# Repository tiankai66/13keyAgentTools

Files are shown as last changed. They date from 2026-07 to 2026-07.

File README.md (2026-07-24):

# 13keyAgentTools

一个面向 Codex、Claude Code、Qoder 等终端工具的开源宏键盘。它本质上是一个可编程宏按键设备，通过标准 USB HID 和可选 USB CDC 与不同 Agent 工作流配合。

本项目采用“3D 打印外壳 + Arduino Micro 手焊 + 可替换固件”的第一版路线，不要求先设计定制 PCB。目标是先做出可靠的通用宏键盘，再逐步增加多 Agent 状态同步、配置工具和可选专用 PCB。

## 当前方案

- 主控：Arduino Micro 兼容板，ATmega32U4，5V / 16MHz，USB-C 数据接口
- 输入：13 键矩阵、1 个 EC11 音量旋钮
- 输出：USB HID 键盘；面板 12 颗独立 RGB 灯显示当前 Agent 剩余用量
- 外壳：OpenSCAD 参数化封闭式盒体，PLA/PETG 3D 打印；紧凑布局
- 固件：Arduino IDE MVP；稳定后迁移到 QMK/Vial
- 主机端：USB CDC 串口状态测试工具；后续接入各 Agent 的 hooks、CLI 事件或桌面自动化

## 目录

```text
13keyAgentTools/
├── mechanical/       3D 打印建模、参数、公差和打印记录
├── hardware/         BOM、手焊接线、测试计划
├── firmware/         Arduino Micro 固件和后续 QMK 迁移位置
├── host/             主机端 RGB 状态桥接和测试工具
├── docs/             工程决策、版本记录和迭代流程
└── .github/          自动检查
```

## 快速开始

1. 先阅读面向新手的 [硬件装配指南](docs/BEGINNER_BUILD_GUIDE.md)，再阅读 [硬件接线说明](hardware/wiring/README.md)。
2. 将 [公差件 STL](mechanical/exports/tolerance_coupon.stl) 导入 Bambu Studio，先验证轴孔和 M3 铜螺母配合。
3. 将 [灯珠承载条](mechanical/exports/pixel_carrier.stl)、[主板透明窗](mechanical/exports/window_lens.stl)、[定位板 STL](mechanical/exports/plate.stl) 和 [下层面板 STL](mechanical/exports/bottom.stl) 导入切片器打印；参数见 [打印计划](mechanical/print/PRINT_PLAN.md)。
4. 也可以用 OpenSCAD 打开 `mechanical/cad/agent_macro.scad`，或运行 `make cad-export` 重新生成 STL。
5. 打印外壳和定位板，先安装 6 个按键、1 个旋钮和 12 颗 RGB 灯中的一小段进行验证。
6. 在 Arduino IDE 中打开 `firmware/arduino/agent_macro_mvp/agent_macro_mvp.ino`。
7. 选择 `Arduino Micro`，上传固件后逐个验证按键、旋钮和面板 RGB 灯。
8. 安装主机端测试工具：

   ```bash
   python3 -m venv .venv
   . .venv/bin/activate
   pip install -r host/agentd/requirements.txt
   python host/agentd/agentd.py --list
   ```

## 版本路线

### Rev 0.1：手焊 MVP

- 6 个按键
- 旋钮
- 单颗 RGB 灯
- Arduino `Keyboard.h`
- 串口发送测试灯效

### Rev 0.2：完整输入设备和用量反馈

- 13 键矩阵和 13 个 1N4148 二极管
- 工作旋钮、音量旋钮、摇杆、TTP223
- 前侧 12 灯 quota 灯带
- PETG 外壳和底壳
- Accept / Reject 使用长按保护

### Rev 0.3：紧凑灯效版

- 移除中心指托，缩短外壳尺寸
- 增加音量 EC11 旋钮
- 12 颗独立可编址 RGB 灯按颗排列，支持用量条渐变显示

### Rev 0.4：面板灯和单旋钮版

- 采用 13 个按键 + 1 个音量旋钮的蓝图式布局
- 移除摇杆、触摸区和多余控制开孔
- 将 12 颗 RGB 灯移到键盘面板，使用一个数据引脚串联控制

### Rev 0.5：按键下置控制板版

- 外壳收缩到约 120 × 100 mm
- 底壳高度增加到 24 mm
- Arduino Micro 放在按键区下方的承托架上
- 右侧只保留窄灯珠轨和音量旋钮，不保留大块空白控制区

### Rev 0.6：双层分体面板版

- 左侧上层面板承载 13 个按键、水平灯带和旋钮
- 右侧示意的下层面板固定 Arduino Micro
- 两块 120 × 95 mm 面板用四角 M3 支柱连接，方便打印、焊接和检修

### Rev 0.6.1：右侧红框主板位

- Arduino Micro 移到右侧空白区下方，避免与按键矩阵重叠
- USB 开口改到右后侧，利用现有空白体积，不增加按键区高度

### Rev 0.7：USB-C 主控接口

- Arduino Micro 兼容板改为 USB-C 数据接口
- 右后侧上、下层面板开口按约 16 × 7 mm 重新导出
- 引脚、固件和矩阵/RGB 接线保持不变，仅更换主控板接口和 USB-C 数据线

### Rev 0.8：前侧供电和主板观察窗

- USB-C 入口调整到图示前侧上边缘，音量旋钮保持在下方
- 右侧主板区域增加透明观察窗
- 13 个按键整体向内收，增加与四角 M3 螺丝的安全距离

### Rev 0.8.1：紧凑 EC11 窗口

- 根据实物照片将旋钮窗口调整为约 12.5 × 12.5 mm 圆角开口
- 保留立式 EC11 结构，缩小窗口而不改变旋钮位置和接线

### Rev 0.8.2：6mm 圆形旋钮轴孔

- 按实物规格将旋钮口改为圆形 6mm 轴孔
- STL 按 6.2mm 导出，适配 FDM 打印公差

### Rev 0.9.4：实测主控与封闭式盒体

- 主控按实物尺寸 35 × 18 × 10 mm 建模，平放在下层盒体内部。
- 下层改为 2.4 mm 底板、16 mm 高的封闭盒底，左右导轨、后挡块和前侧盒壁共同卡住主板。
- Type-C 改为下层前墙 14 × 9 mm 插口，插头从盒体前侧直进，不再依赖上层面板的悬空开口。
- 主板透明窗配套 25.4 × 51.4 × 1.5 mm 透明片，从下方安装后与上层面板一起封闭内部空间；整机装配后是完整盒体。

### Rev 0.3：多 Agent 状态桥

- 主机端接收 Codex、Claude Code、Qoder 等 Agent 的状态
- Raw HID 或 USB CDC 状态协议
- 每个 Agent 独立颜色和等待/运行/完成状态

### Rev 1.0：专用 PCB

- 先保留 Arduino Micro 插座或排针
- 验证无误后再考虑裸 MCU 和集成 USB-C

## 工程原则

- 每个硬件修改先更新 `hardware/wiring/` 和 BOM。
- 每次打印保留耗材、层高、尺寸偏差和照片记录。
- 每次固件修改记录在 `docs/ITERATION_LOG.md`。
- 不把 OpenAI、Anthropic、Qoder、Work Louder 等商标或图标作为项目品牌或商品标识。

## 许可证

本项目新增代码、CAD 和文档默认采用 MIT License，见 [LICENSE](LICENSE)。第三方库和参考项目仍遵循其各自许可证。

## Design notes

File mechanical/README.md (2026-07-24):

# 3D 打印建模

当前使用 OpenSCAD 做参数化 Rev 0.9.4。模型拆成上层控制盖和下层封闭盒底：先打印公差件，再打印灯珠承载条、透明窗、上层控制盖和下层盒体。

## 文件

- `cad/agent_macro.scad`：上层控制盖、下层封闭盒体、主控卡槽、装配预览和公差件。
- `exports/`：可直接导入 Bambu Studio、PrusaSlicer 或 Cura 的 STL 文件。
- `../docs/media/assembly_walkthrough.mp4`：面向新手的封闭盒体装配视频。
- `exports/pixel_carrier.stl`：固定 12 颗独立 RGB 灯珠的承载条。
- `exports/window_lens.stl`：封闭主板观察窗的透明 PETG 镜片；追求清晰度时优先使用亚克力片。
- `tools/generate_stl.py`：无 GUI 环境下的可重复 STL 导出脚本。
- `print/PRINT_PLAN.md`：切片、打印顺序和验收记录模板。

## 设计基准

- 两块面板尺寸：120 × 95 mm。
- 按键间距：19.05 mm。
- MX 轴孔初始尺寸：14.0 mm。
- 上盖厚度：3 mm。
- 下层盒体底板厚度：2.4 mm；盒体高度 16 mm，和 3 mm 上层控制盖装配后总高约 19 mm。
- Arduino Micro 按 35 × 18 × 10 mm 平放，卡槽左右各留 0.6 mm，侧向导轨和后挡块防止主板移动。
- Type-C 插口位于下层盒体前墙，开口约 14 × 9 mm；上层控制盖不再承担 USB 插座受力。
- EC11 使用立式/垂直轴安装，轴线垂直于 3 mm 上层面板；本模型不兼容卧式/侧插编码器。
- 按照片中的小型 EC11 优化为圆形约 6.2 mm 轴孔，适配标称 6 mm 轴，不再使用偏大的方形窗口。
- 上层控制盖右侧保留 24 × 50 mm 主板透明观察窗；透明片改为 25.4 × 51.4 × 1.5 mm，从下方压住窗口边缘，完成封闭。
- 固定方式：M3 螺丝 + 热熔铜螺母。
- 面板 quota RGB 灯：12 个独立窗口，间距 5.3 mm。

这些数值是 Rev 0.9.4 的首件打印基准。主控必须实测为 35 × 18 × 10 mm；不同 USB-C 插座位置的兼容板不能直接套用，先打印公差件和下层盒体做干涉确认。

## 导出

在 OpenSCAD 顶部修改：

```scad
part = "plate";     // plate / bottom / controller_panel / assembly / tolerance / pixel_carrier
```

按 `F6` 渲染后导出 STL。当前 Rev 0.9.4 的 STL 已提交到 `mechanical/exports/`，方便直接下载和导入切片器。为兼容原有链接，`plate.stl` 表示上层控制盖，`bottom.stl` 表示下层封闭盒体。

如果 OpenSCAD 命令行不可用，可安装脚本依赖后执行：

```bash
python3 -m venv /tmp/13key-cad-venv
. /tmp/13key-cad-venv/bin/activate
pip install -r mechanical/tools/requirements.txt
python mechanical/tools/generate_stl.py --part all
```

脚本生成的模型与当前 Rev 0.9.4 的 OpenSCAD 参数保持一致；修改尺寸时需要同步检查两个源文件。

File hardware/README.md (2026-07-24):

# 物理硬件

本项目第一版是手焊结构，不需要定制 PCB。

从零开始装配请先看 [Rev 0.9.4 从 0 到 1 手焊装配说明书](../docs/BEGINNER_BUILD_GUIDE.md)。

## 关键选择

- Arduino Micro 兼容板：ATmega32U4，5V / 16MHz，USB-C 数据接口；实测板体 35 × 18 × 10 mm。
- 13 个物理按键使用 4×4 电气矩阵，因此需要 13 个 1N4148 二极管；面板物理布局为左上 1 键 + 下方 4×3。
- 一个 EC11 音量旋钮和 12 颗 quota RGB 灯数据线使用独立引脚。
- Arduino Micro 平放在封闭式下层盒体的 35 × 18 × 10 mm 卡槽内，左右导轨留 0.6 mm 间隙，USB-C 朝盒体前墙；上层控制盖由四角固定柱锁紧。
- 所有模块共用 GND。

## 接线顺序

1. 先焊 4 行和 4 列矩阵，不接 USB。
2. 万用表逐点确认没有行列短路。
3. 只接 Arduino Micro 和矩阵，上传固件测试按键。
4. 接 EC11 音量旋钮，测试旋转和按压。
5. 最后接 12 颗 quota RGB 灯，限制亮度后再插电脑。

详细引脚见 [wiring/pinout.md](wiring/pinout.md)，采购清单见 [purchase-list.md](purchase-list.md)，结构化物料表见 [bom.csv](bom.csv)。本版本使用封闭式下层盒体；前墙 Type-C 开口和透明主板窗共同完成防止主板外露的盒体结构。

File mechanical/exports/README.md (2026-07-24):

# 可打印模型

这些 STL 是 13keyAgentTools Rev 0.9.4 的可打印导出文件，可直接导入 Bambu Studio、PrusaSlicer、Cura 等切片器。

| 文件 | 用途 | 外形尺寸 |
|---|---|---|
| `tolerance_coupon.stl` | 轴孔和 M3 热熔螺母公差测试 | 70 × 42 × 4 mm |
| `plate.stl` | 上层控制盖：13 键、6 mm 圆形 EC11 轴孔、水平 12 灯窗和主板透明窗 | 120 × 95 × 3 mm |
| `bottom.stl` | 下层封闭盒体：2.4 mm 底板、16 mm 盒体高度、35×18×10 mm 主控卡槽和前墙 Type-C 插口 | 120 × 95 × 16 mm |
| `pixel_carrier.stl` | 水平排列的 12 颗独立 RGB 灯珠承载条 | 67.3 × 8 × 2 mm |
| `window_lens.stl` | 封闭主板透明观察窗，可用透明 PETG 打印 | 25.4 × 51.4 × 1.5 mm |

打印顺序：先打印 `tolerance_coupon.stl`，再打印 `pixel_carrier.stl`、`window_lens.stl` 和 `bottom.stl` 做尺寸验证，最后打印 `plate.stl`。`bottom.stl` 是封闭式盒底，`plate.stl` 是带透明观察窗的上层控制盖。

STL 是当前 Rev 0.9.4 的导出物；参数源文件仍在 [../cad/agent_macro.scad](../cad/agent_macro.scad)，导出脚本在 [../tools/generate_stl.py](../tools/generate_stl.py)。主控卡槽和 Type-C 插口仍需用实物首件确认。

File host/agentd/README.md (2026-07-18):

# agentd：多 Agent 主机端状态测试工具

当前版本只负责验证 Arduino Micro 的 USB CDC 串口和 RGB 协议，不直接读取某一个 Agent 的状态。后续可以将 Codex CLI、Claude Code、Qoder 或其他 coding agent 的 hooks、CLI 事件或桌面自动化适配到同一个协议。

## 安装

```bash
python3 -m venv .venv
. .venv/bin/activate
pip install -r host/agentd/requirements.txt
```

## 使用

列出串口：

```bash
python host/agentd/agentd.py --list
```

交互控制：

```bash
python host/agentd/agentd.py --port /dev/cu.usbmodemXXXX
```

输入：

```text
LED 0 thinking
LED 1 running
LED 2 waiting
LED 3 done
QUOTA 42
CLEAR
```

快速设置当前 Agent 的剩余用量：

```bash
python host/agentd/agentd.py --port /dev/cu.usbmodemXXXX --quota 42
```

自动灯效演示：

```bash
python host/agentd/agentd.py --port /dev/cu.usbmodemXXXX --demo
```

颜色协议：

| 状态 | 颜色 |
|---|---|
| idle | 白色 |
| thinking | 蓝色 |
| running | 紫色 |
| waiting | 黄色 |
| done | 绿色 |
| error | 红色 |

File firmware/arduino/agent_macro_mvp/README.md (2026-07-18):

# Arduino Micro Rev 0.5 MVP 固件

这是 Rev 0.5 的 Arduino IDE 固件，不依赖定制 PCB。

## 上传

1. 安装 Arduino IDE。
2. 打开 `agent_macro_mvp.ino`。
3. 选择 `Tools > Board > Arduino Micro`。
4. 选择对应串口并上传。
5. 如果上传时端口消失，快速按两次 Arduino Micro 的 Reset，再选择 Bootloader 端口。

## 当前行为

- A：Enter / Accept
- B：Esc / Reject
- C：Ctrl+N / New Chat
- D：Ctrl+Shift+D / Push-to-talk
- E～M：F1～F9，留给主机端工作流映射
- 音量旋钮：F11/F12 临时占位，后续改为 USB Consumer volume up/down

以上快捷键是 MVP 占位符；不同 Agent 终端的实际快捷键应在主机端确认后再固化，固件本身保持通用 HID 宏键盘定位。

## RGB

默认 `ENABLE_RGB` 为 `0`，这样可以先不安装 RGB 库和 RGB 灯测试按键/旋钮输入。

需要灯光时：

1. 安装 Arduino Library Manager 中的 `Adafruit NeoPixel`。
2. 将 `ENABLE_RGB` 改为 `1`（当前硬件为 12 颗独立 RGB 灯）。
3. 使用 `host/agentd/agentd.py` 发送 `LED` 或 `QUOTA` 命令。

`QUOTA 0`～`QUOTA 100` 会把面板 12 颗独立 RGB 灯显示为剩余用量条：0% 全灭，100% 全亮；中间像素按百分比部分亮起，颜色在红、黄、绿之间渐变。首版亮度限制为 32/255，避免 USB 供电过载。

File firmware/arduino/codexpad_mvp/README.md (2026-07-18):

# Arduino Micro MVP 固件

这是 Rev 0.1 的 Arduino IDE 固件，不依赖定制 PCB。

## 上传

1. 安装 Arduino IDE。
2. 打开 `codexpad_mvp.ino`。
3. 选择 `Tools > Board > Arduino Micro`。
4. 选择对应串口并上传。
5. 如果上传时端口消失，快速按两次 Arduino Micro 的 Reset，再选择 Bootloader 端口。

## 当前行为

- A：Enter / Accept
- B：Esc / Reject
- C：Ctrl+N / New Chat
- D：Ctrl+Shift+D / Push-to-talk
- E～M：F1～F9，留给主机端工作流映射
- 旋钮：F11/F12，留给 reasoning level 映射
- 触摸：F10，切换 Layer
- 摇杆：F1～F4，分别代表 Review、Debug、Refactor、Test

这些快捷键是 MVP 占位符。Codex App 或 Codex CLI 的实际快捷键应在主机端确认后再固化。

## RGB

默认 `ENABLE_RGB` 为 `0`，这样可以先不安装 RGB 库和灯珠测试输入。

需要灯光时：

1. 安装 Arduino Library Manager 中的 `Adafruit NeoPixel`。
2. 将 `ENABLE_RGB` 改为 `1`。
3. 将 `RGB_COUNT` 改为实际灯珠数量。
4. 使用 `host/codexd/codexd.py` 发送 `LED` 命令。

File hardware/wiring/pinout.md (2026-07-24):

# Rev 0.9.4 引脚表

以下是 Arduino Micro 的 Arduino 引脚命名。`A0`～`A3` 既可以作模拟输入，也可以作为数字输入/输出；本项目按具体功能使用。

| 功能 | Arduino 引脚 | 方向 | 说明 |
|---|---:|---|---|
| Matrix row 0 | D4 | 输出 | 逐行扫描 |
| Matrix row 1 | D5 | 输出 | 逐行扫描 |
| Matrix row 2 | D6 | 输出 | 逐行扫描 |
| Matrix row 3 | D7 | 输出 | 逐行扫描 |
| Matrix col 0 | D8 | 输入上拉 | 读取按键 |
| Matrix col 1 | D9 | 输入上拉 | 读取按键 |
| Matrix col 2 | D10 | 输入上拉 | 读取按键 |
| Matrix col 3 | D11 | 输入上拉 | 读取按键 |
| Volume encoder A | D2 | 输入上拉 | 音量旋转 |
| Volume encoder B | D3 | 输入上拉 | 音量旋转 |
| Volume encoder push | D12 | 输入上拉 | 音量旋钮按下 |
| Quota RGB pixel DIN | A3 | 输出 | 12 颗 WS2812B / SK6812 独立灯珠串联数据 |

## Rev 0.9.4 封闭盒体布局

```text
[左上 1 键] [12 颗水平面板 RGB quota 灯][音量旋钮]
[        4 × 3 按键矩阵        ]
[上层控制盖：按键、旋钮、水平 RGB 和透明主板窗]
[下层封闭盒体：35×18×10 mm Arduino Micro 卡槽 + 前墙 Type-C 开口]
```

音量旋钮使用 D2/D3/D12。面板上的 12 颗 RGB 灯使用 A3 串联，按灯珠顺序从左到右显示剩余用量；12 颗灯共用一个数据引脚，通过 DIN/DOUT 串联，不占用 12 个 GPIO。

Arduino Micro 平放在下层封闭盒体的卡槽内，左右导轨和后挡块负责限位，USB-C 由前墙 14×9 mm 开口引出。建议先将板卡和 USB 线固定，再从下方安装透明窗片，最后把上层控制盖通过四角 M3 螺丝锁紧。

## 矩阵位置

电气矩阵中的 4×4 位置如下，`--` 是未安装的电气位置；面板物理布局与此一致：

```text
[ A ][ --][ --][ --]
[ B ][ C ][ D ][ E ]
[ F ][ G ][ H ][ I ]
[ J ][ K ][ L ][ M ]
```

如果后续改成 2U 键帽，先保留两个独立开关，等固件确认后再把它们映射为同一个动作。

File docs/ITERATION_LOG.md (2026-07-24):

# 迭代记录

## 2026-07-18 — 0.1.0

### 决策

- 新建独立工程 `13keyAgentTools`，不修改同级的旧 `project/` 目录。
- 第一版采用 Arduino Micro，而不是直接设计专用 PCB。
- 13 个按键采用 4×4 矩阵，控制设备占用独立引脚。
- 第一版使用 USB 有线连接，不引入蓝牙、电池和充电电路。

### 下一步

- 打印 `mechanical/cad/agent_macro.scad` 的 `tolerance` 部件。
- 采购并测试 6 个按键、1 个 EC11、1 个 Arduino Micro。
- 在没有 RGB 的情况下完成矩阵和旋钮输入验证。

## 2026-07-18 — 0.2.0 设计迭代

### 决策

- 将外壳加宽为 184 × 112 mm，在按键区和控制区之间加入低矮中心指托与凸起定位点。
- 增加第二个 EC11，独立预留给系统音量；当前固件先用 F11/F12 占位。
- 前侧加入 12 灯 WS2812B/SK6812 灯带窗口，用 `QUOTA 0..100` 显示当前 Agent 剩余用量。
- 灯带亮度限制为 32/255，优先保证 USB 供电和键盘输入稳定。

### 下一步

- 打印 Rev 0.2 公差件和外壳，验证中心指托高度、旋钮间距及灯带窗口。
- 采购两个 EC11 和一段 12 灯 5V 灯带，完成 D2/D3/D12 与 A3 的手焊。

## 2026-07-18 — 0.3.0 紧凑灯效版

### 决策

- 移除中心指托，不再为手指承托区扩大外壳，恢复紧凑型布局，外壳调整为 164 × 104 mm。
- 保留第二个 EC11，作为未来音量控制旋钮；固件暂用 F11/F12 占位。
- 用 12 颗独立可编址 RGB 灯替代单一状态灯，硬件上可使用独立灯珠或裁切后的 12 像素彩色灯带。
- 用量条支持中间像素部分亮起，并按剩余量在红、黄、绿之间渐变，降低跳变感。

## 2026-07-18 — 0.4.0 面板灯和单旋钮版

### 决策

- 采用 13 个按键 + 1 个 EC11 音量旋钮的紧凑布局，参考蓝色布局图重新安排面板。
- 删除摇杆、TTP223 和多余旋钮开孔；这些功能不属于当前版本的两个核心需求。
- 将 12 颗 RGB 灯从前/后侧移到键盘面板，并按一字排列显示剩余用量。
- 12 颗灯使用 DIN/DOUT 串联，只占 Arduino Micro 的 A3 一个数据引脚；供电和地线并联。

## 2026-07-18 — 0.5.0 按键下置控制板版

### 决策

- 将外壳收缩为约 120 × 100 mm：13 个按键占主体区域，右侧只留窄灯珠轨和一个音量旋钮。
- 底壳高度从 18 mm 增加到 24 mm，在按键区下方增加通用 48 × 18 mm Arduino Micro 承托架。
- 继续使用单 A3 数据引脚串联 12 颗 RGB 灯，避免逐颗灯珠占用 Arduino Micro GPIO。
- 新增 `pixel_carrier.stl`，先固定灯珠和灯珠间距，再将承载条贴装到面板下方。

## 2026-07-18 — 0.6.0 双层分体面板版

### 决策

- 将原来的封闭式底壳改为两块独立面板：上层面板承载全部交互件，下层面板固定 Arduino Micro。
- 上层面板改为左上 1 键 + 下方 4×3 按键矩阵，顶部横向布置 12 颗 RGB 灯和 1 个 EC11，去掉右侧大块空白。
- 下层面板使用 4 个集成 M3 支柱连接上层面板，并用通用 18 × 48 mm 承托架固定 Arduino Micro，避免依赖不同克隆板的安装孔距。
- 两块面板保持 120 × 95 mm；下层面板总高 14 mm（4 mm 面板 + 10 mm 支柱），便于打印和检修。
- 保留后侧 USB 开口；当前主控仍是 Micro-USB Arduino Micro，开口为未来 USB-C 变体留出余量。

## 2026-07-18 — 0.6.1 红框区域主板位修正

### 修正

- 将 Arduino Micro 承托架从面板中部移到右侧红框空白区下方，避免主板与按键矩阵上下重叠。
- 主板保持竖向 18 × 48 mm，位置为右侧空白区；USB 接口改为右后侧开口。
- 上层面板仍保持 120 × 95 × 3 mm，不为按键区增加高度；下层面板的 10 mm 检修间隙仅服务于主板和走线。

## 2026-07-18 — 0.7.0 USB-C 主控接口版

### 修正

- Arduino Micro 兼容板从 Micro-USB 改为 USB-C 数据接口，电气规格仍为 ATmega32U4、5V、16MHz。
- 右后侧上层面板和下层主板面板的 USB 开口按约 16 × 7 mm 重新建模并重新导出 STL。
- 采购清单改用 USB-C 数据线；矩阵、EC11、RGB 灯、Arduino 引脚和固件无需修改。

## 2026-07-19 — 0.8.0 前侧供电和主板观察窗版

### 决策

- 按示意图将 USB-C 电源入口定义在图示前侧上边缘，音量旋钮保持在下方，避免电源线与旋钮区域混在一起。
- 在右侧 Arduino Micro 区域增加 24 × 50 mm 透明主板观察窗，默认配套 23.4 × 49.4 × 1.5 mm 镜片；透明亚克力优先，透明 PETG 可作为打印替代。
- 将按键起始坐标由 10 × 8 mm 内移至 12 × 10 mm，增加左上按键与四角 M3 螺丝的安全距离。
- 新增 `window_lens.stl`，并重新导出上层面板和下层主板面板。

## 2026-07-22 — 0.8.1 紧凑 EC11 窗口版

### 修正

- 根据用户实际购买的小型立式 EC11 实物照片，移除原先偏大的 12 × 16 mm 长方形开口。
- 新开口改为约 12.5 × 12.5 mm 圆角窗口，让编码器本体通过、面板保留更多实体支撑。
- 右侧主板透明观察窗、USB-C 前侧入口、按键位置和矩阵接线保持不变。

## 2026-07-23 — 0.8.2 6mm 圆形旋钮轴孔版

### 修正

- 根据用户确认，旋钮口改为圆形，标称直径 6mm。
- 3D 打印模型按 6.2mm 导出，为 FDM 打印预留约 0.2mm 间隙。
- EC11 本体继续安装在面板下方，只有轴和旋钮从面板上方露出；主板透明窗和其他布局不变。

## 2026-07-23 — 手焊装配说明书与矩阵映射校正

### 修正

- 新增带示意图的从 0 到 1 手焊说明书，明确两针按键无极性、二极管独立串联以及黑环朝行线。
- 新增装配层次、矩阵、EC11 和 RGB 接线 SVG 图，覆盖主控板与灯带尚未到货时可先完成的步骤。
- 将固件矩阵动作表对齐当前实际面板：左上 A，下面 B–M 的 4×3 布局。

## 2026-07-23 — 参考图风格完整焊接海报

### 交付

- 新增 `docs/diagrams/full_wiring_poster.png`，按用户提供的参考图风格绘制完整装配与接线海报。
- 海报包含透明上层面板、13 个两针按键和二极管、D4–D11 矩阵、立式 EC11、A3 RGB 数据线、330Ω 电阻、1000µF 电容、5V/GND 和 Arduino Micro USB-C 主板。
- 说明书入口改为优先显示这张海报，原 SVG 图保留为可放大编辑的补充资料。

## 2026-07-24 — 0.9.4 实测主控与封闭式盒体

### 结构调整

- 根据到货主控实测尺寸，将 Arduino Micro 卡槽改为 35 × 18 × 10 mm，主板平放在右侧盒体内部。
- 下层从开放式主板面板改为封闭盒底：2.4 mm 底板、16 mm 盒体高度、侧壁和四角上盖固定柱。
- 主板卡槽左右各留 0.6 mm，加入两条高侧导轨和后挡块，前端保持 Type-C 直线插拔通道。
- Type-C 改为下层盒体前墙 14 × 9 mm 开口，插拔力由盒体承受，不再让主板 USB 焊盘承受侧向力。
- 透明观察窗改用 25.4 × 51.4 × 1.5 mm 镜片，从下方压住 24 × 50 mm 窗口；安装后主板不外露，整机成为封闭式盒体。

### 重新打印和验收

- 重新导出 `bottom.stl`、`plate.stl` 和 `window_lens.stl`；`pixel_carrier.stl`、公差件仍需按当前目录重新确认。
- 首件优先试装主控卡槽和 Type-C 插头，再焊接和整理全部线束，最后安装透明窗并合盖。

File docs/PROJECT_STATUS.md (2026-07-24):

# 项目状态

当前版本：`0.9.4-closed-box-controller-cradle`

## 已完成

- 独立 Git 项目目录和远程仓库连接
- Arduino Micro 5V/16MHz 方案
- 13 键矩阵接线定义：左上 1 键 + 下方 4×3
- EC11 和面板 RGB 灯引脚定义
- OpenSCAD 参数化外壳初稿
- 13 键 + 1 个音量旋钮的紧凑型布局
- 面板上的 12 颗独立 RGB quota 灯布局
- 可打印的 12 灯珠承载条，解决逐颗灯珠的面板定位
- 封闭式下层盒体、35×18×10 mm Arduino Micro 卡槽和四角上盖固定柱
- Bambu Studio 可导入的 Rev 0.9.4 USB-C 封闭式盒体 STL 导出链路
- 前侧 USB-C 入口、主板透明观察窗和按键/螺丝安全间距优化
- 主板左右 0.6 mm 装配间隙、侧向导轨和后挡块已加入下层承托
- 根据实物照片将 EC11 窗口改为约 6.2 mm 的圆形轴孔
- Arduino IDE MVP 固件骨架
- 主机端 USB CDC 灯效测试工具

## 尚未验证

- Rev 0.9.4 首件与实际主控 USB-C 插座、卡槽、透明窗和上盖内侧的尺寸配合
- 二极管方向和矩阵扫描
- Arduino Micro 与所有输入设备同时工作时的电流余量
- 12 颗 RGB 灯满亮度下的 USB 供电能力
- 各 Agent CLI 的最终状态 hooks

## 当前不做

- 蓝牙和电池
- 裸 ATmega32U4 专用 PCB
- 任一厂商的官方图标键帽
- 自动批准 Agent 操作

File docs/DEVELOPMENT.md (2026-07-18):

# 开发与迭代流程

## 分支

- `main`：可复现、可使用的版本。
- `agent/<topic>`：每个独立功能或硬件改版。
- 机械、硬件、固件尽量使用不同分支，减少互相覆盖。

## 提交信息

采用简短前缀：

```text
mech: adjust switch cutout tolerance
hw: add encoder wiring revision
fw: debounce matrix keys
host: add serial LED demo
docs: record Rev 0.2 test result
```

## 每次迭代必须记录

- 改了什么
- 为什么改
- 使用的材料或器件
- 测试方法
- 通过/失败结果
- 下一步动作

## 硬件安全

- 焊接或改线前拔掉 USB。
- RGB 供电必须和 Arduino Micro 共地。
- 不要把 LED 大电流直接从 3.3V 供电。
- Accept / Reject 等有副作用的动作使用长按或二次确认。

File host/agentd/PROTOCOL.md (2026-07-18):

# USB CDC 状态协议 Rev 0.5

Arduino Micro 的 `Serial` 对象对应 USB CDC 虚拟串口。每条命令以换行结束。

## 设置单颗灯

```text
LED <index> <red> <green> <blue>
```

例如：

```text
LED 0 0 64 255
```

## 清除全部灯

```text
CLEAR
```

## 设置剩余用量条

```text
QUOTA <percent>
```

例如：

```text
QUOTA 42
```

当前 Rev 0.5 使用面板上的 12 颗独立可编址 RGB 灯作为当前 Agent 的剩余用量条：0% 全灭，100% 全亮。中间像素会按百分比部分亮起，颜色在红色、黄色和绿色之间渐变；后续可扩展为多个 Agent 分段显示。

## 设计边界

- 本协议只控制硬件灯光，不负责批准或拒绝 Agent 操作。
- 各 Agent 的状态适配器应放在主机端，不应把 API 密钥或业务逻辑写进 MCU。
- 后续如果 USB CDC 延迟或带宽不足，再迁移到 Raw HID；硬件引脚不需要改变。

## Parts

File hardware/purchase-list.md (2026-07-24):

# Rev 0.9.4 硬件采购清单

本清单对应当前紧凑型版本：**13 个按键 + 1 个 EC11 旋钮 + 面板 12 颗独立可编址 RGB 灯 + 封闭盒体内的 Arduino Micro**。

这一版不需要定制 PCB。Arduino Micro 固定在下层封闭盒体的 35×18×10 mm 卡槽内，矩阵和灯珠均采用手焊连接。

## 一、必须采购

| 类别 | 物料 | 规格/验收要点 | 装机数量 | 建议采购量 |
|---|---|---|---:|---:|
| 主控 | Arduino Micro 兼容板 | **ATmega32U4、5V、16MHz、USB-C 数据接口**，最好带排针；板体实测 35×18×10mm，USB-C 位于短边 | 1 | 1 |
| 按键 | 机械轴体 | MX 兼容、1U，任意手感均可 | 13 | 15 |
| 键帽 | 1U 键帽 | MX 兼容，13 个同规格或按键帽方案搭配 | 13 | 13–15 |
| 二极管 | 1N4148 | 直插信号二极管，每个按键 1 个 | 13 | 15–20 |
| 旋钮 | EC11 立式/垂直型 | **5 脚、带按压开关、面板螺纹套管和螺母、6mm 轴**；建议 15mm 左右轴长 | 1 | 1–2 |
| RGB 灯 | WS2812B / SK6812 | **5V、可编址、独立像素**；优先选择 5mm 级小型灯珠模块 | 12 | 14 |
| 限流/信号电阻 | 电阻 | 330Ω，1/4W，串在第一颗 RGB 灯的 DIN | 1 | 5–10 |
| 电源滤波 | 电解电容 | 1000µF，耐压不低于 6.3V，建议 10V，跨接 RGB 的 5V/GND | 1 | 2 |
| 导线 | 多色软线 | 26–30AWG，至少包含红、黑及 4 种矩阵配色 | 约 3m | 1 套 |
| 固定 | M3 热熔螺母 | 黄铜，适配打印件 | 4 | 6–10 |
| 固定 | M3 螺丝 | **M3×16mm**，穿过上层控制盖并锁入下层封闭盒体固定柱 | 4 | 6–10 |
| 连接 | USB-C 数据线 | 必须支持数据传输，不要只买充电线；建议直头、长度 1m 左右 | 1 | 1–2 |

### RGB 灯的特别说明

当前面板灯窗中心距约 **5.3mm**，并配有专用的 [pixel carrier](../mechanical/exports/pixel_carrier.stl) 承载条。因此下单前必须确认灯珠或小模块的外形尺寸能够放入约 5mm 宽的窗口，并且可以逐颗连接 `DIN → DOUT`。

### USB-C 主控板验收

- 必须是 Arduino Micro 的 **ATmega32U4 / 5V / 16MHz** 兼容板，不要用 ATmega328P、3.3V/8MHz 或仅支持充电的 USB-C 板。
- 板体必须与实物一致为约 35×18×10mm，USB-C 接口位于短边，并朝向盒体前墙。
- USB-C 插头外壳不能超过下层盒体前墙约 14×9mm 的开口；插拔力由盒体承受，不应传到主板焊盘。
- USB-C 只是连接器变化，Arduino 引脚、矩阵接线、RGB 接线和固件无需改变。

不要直接购买常见的 30灯/米或 60灯/米灯带，除非卖家明确给出像素中心距并确认与 5.3mm 布局匹配。普通灯带的像素间距通常不能直接装入当前承载条。

如果采购到的是 12 像素可裁切灯带，也可以作为替代方案，但需要先在 [tolerance coupon](../mechanical/exports/tolerance_coupon.stl) 或废料上验证间距和发光位置。

### EC11 旋钮的特别说明

当前 3D 模型是**立式/垂直轴**安装：旋钮轴线垂直于上层面板，从面板上方伸出；编码器本体和焊脚位于面板下方。

请选择：

- `EC11 vertical`、`EC11 立式`、`EC11 垂直安装`
- 带按压开关的 5 脚版本
- 带面板螺纹套管和螺母，套管外径不超过约 8mm
- 6mm 圆轴或 D 轴，轴长建议约 15mm
- 旋钮轴为 6mm；当前模型圆孔按约 6.2mm 导出，给 FDM 打印留 0.2mm 间隙

不要购买 `EC11 horizontal`、`卧式`、`侧插` 或“轴线与 PCB 平行”的版本。当前设计没有为卧式编码器预留侧向安装空间，也没有单独的编码器 PCB。

## 二、建议同时采购的焊接和装配辅料

| 物料 | 建议数量 | 用途 |
|---|---:|---|
| 63/37 或无铅焊锡丝 | 1 卷 | 矩阵、旋钮和 RGB 灯焊接 |
| 助焊剂 | 1 瓶/笔 | 改善密集焊点可靠性 |
| 热缩管 | 1 套 | RGB 电源、信号和旋钮引线绝缘 |
| 洞洞板或小块接线板 | 1 小块，可选 | 组织 5V/GND 汇流，非必需 |
| 2.54mm 排针/排母 | 1 套，可选 | 让 Arduino、RGB 灯链和旋钮便于拆装 |
| 透明/半透明薄片 | 1 小片，可选 | 放在面板灯窗下做柔光，建议 0.3–1mm |
| 主板透明观察窗 | 1 片 | 透明亚克力优先；或透明 PETG 打印，约 25.4×51.4×1.5mm，从上层控制盖下方安装 |
| 双面胶或薄型泡棉胶 | 1 卷 | 固定 RGB 承载条；主控板由下层盒体卡槽固定，不靠胶水 |
| 防滑硅胶脚垫 | 4 个 | 粘在封闭盒体底部四角 |

## 三、已有工具即可，不必重复购买

- 电烙铁、烙铁架和海绵/清洁铜丝
- 万用表
- 斜口钳、剥线钳、尖嘴钳
- 镊子和小号螺丝刀
- 热风枪或打火机（用于热缩管）
- 3D 打印机和适合面板/底壳的耗材

## 四、这版不需要采购的东西

- 不需要定制 PCB。
- 不需要另外购买 Arduino Micro 的 M2/M2.5 固定螺丝；下层盒体使用打印的 35×18×10 mm 卡槽、侧导轨和后挡块固定主板。
- 不需要 12 个独立的 Arduino GPIO；12 颗 RGB 灯通过 `DIN/DOUT` 串联，只使用 Arduino Micro 的 **A3** 作为数据线。
- 不需要摇杆、TTP223 触摸模块、额外的工作流旋钮或右侧扩展按键。
- 不需要外接电源即可完成首轮低亮度测试；固件默认将 RGB 亮度限制在 32/255。未来如果需要长时间高亮或全白显示，再增加稳定的 5V 外部供电，并与 Arduino 共地。

## 五、接线验收顺序

1. 先只焊 13 个按键的 4×4 矩阵和 13 个二极管。
2. 用万用表确认行列之间没有短路，再连接 Arduino Micro 并测试按键。
3. 接 EC11 的 A/B/按压端，分别对应 D2、D3、D12。
4. 将 RGB 的 DIN 接 A3，所有灯共用 5V 和 GND，逐颗按 `DIN → DOUT` 串接。
5. 第一颗灯的 DIN 串入 330Ω 电阻，RGB 电源入口并联 1000µF 电容。
6. 最后插入电脑，先用低亮度测试单颗灯、整条灯链和 `QUOTA` 显示。

完整引脚表见 [wiring/pinout.md](wiring/pinout.md)，结构打印文件见 [机械打印文件](../mechanical/exports/README.md)，原始表格见 [bom.csv](bom.csv)。

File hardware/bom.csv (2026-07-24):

category | part | spec | qty | required | notes
controller | Arduino Micro compatible board | ATmega32U4 5V 16MHz USB-C data interface with headers | 1 | yes | Measured board outline 35x18x10 mm; do not substitute ATmega328P or 3.3V/8MHz
switch | Mechanical switch | MX-compatible or low-profile switch | 13 | yes | Rev 0.7 uses individual 1U positions
keycap | Keycap | MX-compatible 1U | 13 | yes | Use 2U visual key only after matrix is stable
diode | 1N4148 | Through-hole signal diode | 13 | yes | One diode per switch
encoder | EC11 vertical | 5-pin small-body rotary encoder with push switch | 1 | yes | 6 mm shaft; panel hole is circular about 6.2 mm for FDM clearance; do not buy horizontal/side-mount type
rgb | WS2812B or SK6812 RGB pixels | 5V individually addressable RGB pixels or a cut 12-pixel strip | 12 | yes | Panel quota bar; chain DIN/DOUT and cap brightness
passive | Data resistor | 330 ohm in series with LED DIN | 1 | yes | Place close to the first LED
passive | Electrolytic capacitor | 1000 uF 6.3 V or higher across LED 5V/GND | 1 | yes | Place near the strip power entry
wire | Hook-up wire | 26-30 AWG stranded | 1 set | yes | Use separate colors for rows and columns
fastener | M3 heat-set insert | Brass insert | 4 | yes | Tune hole with tolerance coupon
fastener | M3 screw | M3x16 mm for the closed lower box and upper control lid | 4 | yes | Printed corner bosses retain the lid; verify engagement after printing
foot | Silicone feet | Adhesive or press-fit | 4 | optional | Prevent desk sliding
power | USB data cable | USB-C | 1 | yes | Use a known data cable; straight plug preferred for the front opening
panel | Controller inspection window | Clear acrylic or transparent PETG about 25.4x51.4x1.5 mm | 1 | yes | Installed from below to close the 24x50 mm upper-lid window

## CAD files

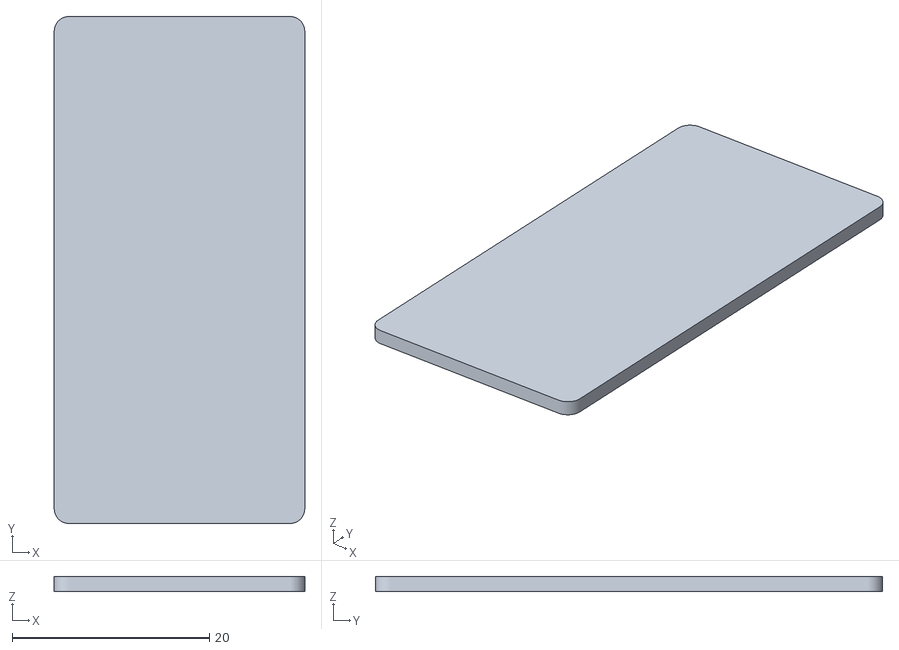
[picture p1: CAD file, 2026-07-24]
mechanical/exports/window_lens.stl
25.4 x 51.4 x 1.50

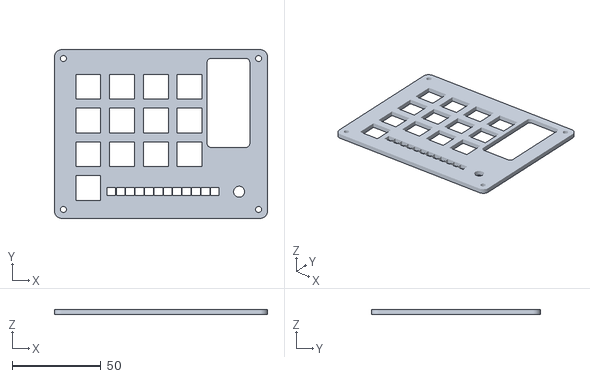
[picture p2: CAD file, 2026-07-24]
mechanical/exports/plate.stl
120.0 x 95.0 x 3.00

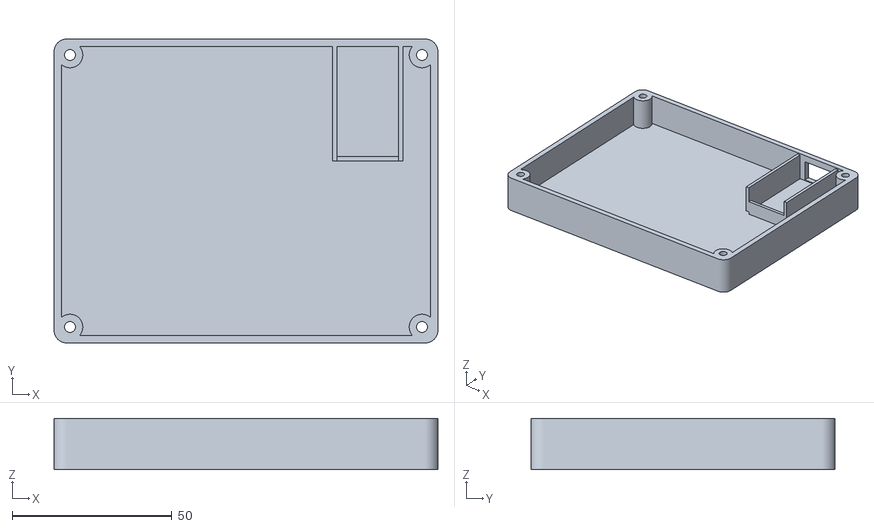
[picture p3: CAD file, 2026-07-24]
mechanical/exports/bottom.stl
120.0 x 95.0 x 16.0

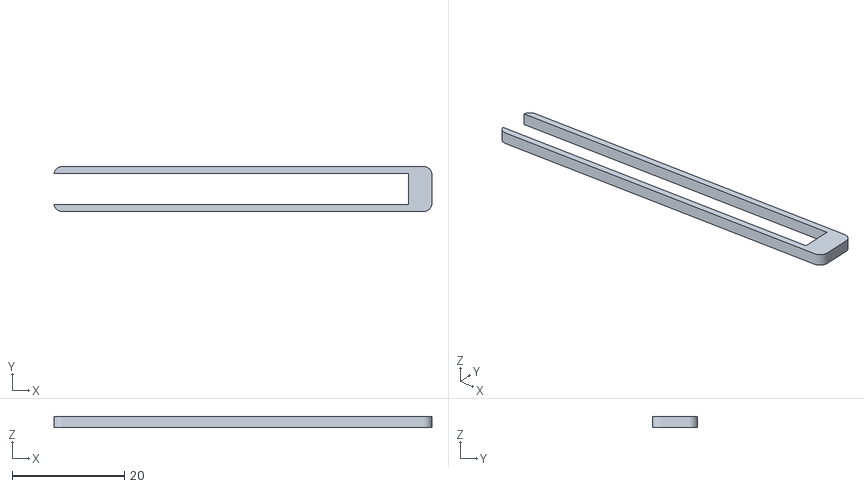
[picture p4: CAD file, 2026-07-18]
mechanical/exports/pixel_carrier.stl
67.3 x 8.00 x 2.00

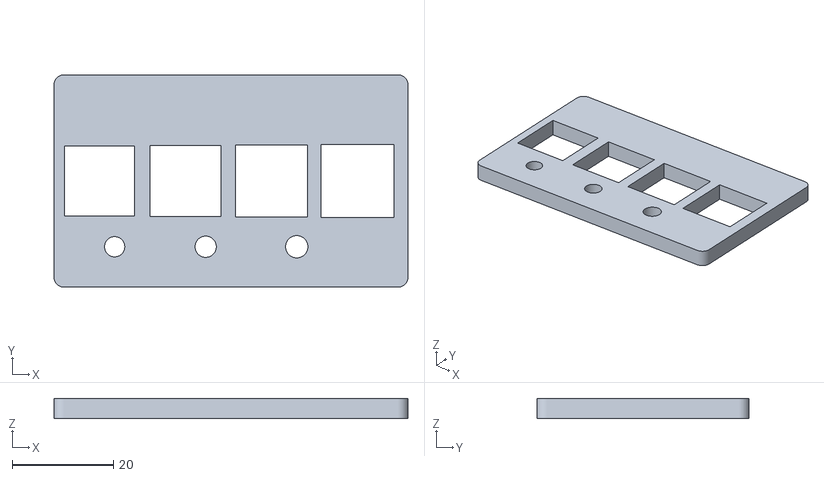
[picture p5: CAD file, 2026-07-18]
mechanical/exports/tolerance_coupon.stl
70.0 x 42.0 x 4.00

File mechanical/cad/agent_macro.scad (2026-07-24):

// 13keyAgentTools Rev 0.9.4
// Closed-box layout: controls on the upper lid, Arduino Micro inside the lower box.
// Export one part at a time by changing `part`.

part = "plate"; // plate / bottom / controller_panel / assembly / tolerance / pixel_carrier / window_lens

$fn = 48;

case_w = 120;
case_d = 95;
plate_t = 3.0;
bottom_floor_t = 2.4;
bottom_wall_t = 2.4;
bottom_box_h = 16.0;
corner_r = 4.0;

// Measured USB-C Arduino Micro compatible board. The board lies flat inside
// the closed lower box; its short USB-C end faces the front wall.
controller_board_w = 18;
controller_board_l = 35;
controller_board_h = 10;
controller_board_x = 89;
controller_board_y = 57.5;
controller_usb_x = 98;
controller_usb_opening_w = 14;
controller_usb_opening_d = 5;
controller_usb_opening_z = 4.0;
controller_usb_opening_h = 9.0;
controller_board_clearance = 0.6;

// Clear inspection window above the controller board.
controller_window_x = 98;
controller_window_y = 65;
controller_window_w = 24;
controller_window_d = 50;
window_lens_t = 1.5;
// The lens overlaps the 24 x 50 mm opening by 0.7 mm on each side so the
// controller window is closed when the lens is installed from below.
window_lens_w = 25.4;
window_lens_d = 51.4;

key_pitch = 19.05;
key_hole = 14.0;
// One vertical EC11 encoder, reserved for future system-volume control.
// The shaft is perpendicular to the upper panel; the body is below the panel.
volume_encoder = [104, 15];
// Nominal 6 mm encoder shaft; 0.2 mm clearance is intentional for FDM.
encoder_shaft_hole_d = 6.2;

// Twelve individually addressable RGB pixels on a horizontal top-panel rail.
quota_led_count = 12;
quota_led_start_x = 32;
quota_led_y = 15;
quota_led_pitch = 5.3;
quota_led_window_w = 5;
quota_led_window_d = 4.5;

// One key in the top-left plus a compact 4 x 3 matrix below it: 13 individual 1U keys.
key_positions = [
    [0, 0],
    [0, 1], [1, 1], [2, 1], [3, 1],
    [0, 2], [1, 2], [2, 2], [3, 2],
    [0, 3], [1, 3], [2, 3], [3, 3]
];
// Inset the key field so the top-left key is not crowded by the M3 corner screw.
key_origin = [12, 10];

screw_positions = [
    [5, 5],
    [case_w - 5, 5],
    [5, case_d - 5],
    [case_w - 5, case_d - 5]
];

module rounded_prism(w, d, h, r) {
    linear_extrude(height = h)
        offset(r = r)
            offset(delta = -r)
                square([w, d], center = false);
}

module key_holes(extra = 1) {
    for (p = key_positions) {
        translate([
            key_origin[0] + p[0] * key_pitch,
            key_origin[1] + p[1] * key_pitch,
            -extra
        ])
            cube([key_hole, key_hole, plate_t + 2 * extra], center = false);
    }
}

module screw_holes(extra = 1, height = plate_t + 2) {
    for (p = screw_positions) {
        translate([p[0], p[1], -extra])
            cylinder(d = 3.4, h = height);
    }
}

module usb_opening(extra = 1, height = plate_t + 2) {
    // Type-C opening belongs to the lower box front wall, not the upper lid.
    translate([
        controller_usb_x - controller_usb_opening_w / 2,
        case_d - controller_usb_opening_d,
        controller_usb_opening_z
    ])
        cube([controller_usb_opening_w, controller_usb_opening_d, controller_usb_opening_h], center = false);
}

module controller_window(extra = 1) {
    // Through-window for a clear acrylic or transparent PETG lens.
    translate([
        controller_window_x - controller_window_w / 2,
        controller_window_y - controller_window_d / 2,
        -extra
    ])
        rounded_prism(controller_window_w, controller_window_d, plate_t + 2 * extra, 2);
}

module window_lens() {
    // Clear PETG lens or acrylic insert; it is part of the closed enclosure.
    translate([
        controller_window_x - window_lens_w / 2,
        controller_window_y - window_lens_d / 2,
        0
    ])
        rounded_prism(window_lens_w, window_lens_d, window_lens_t, 1.5);
}

module control_holes(extra = 1) {
    // Circular opening for the photographed 6 mm vertical EC11 shaft.
    // The encoder body stays below the panel and the shaft/knob stays above.
    translate([volume_encoder[0], volume_encoder[1], -extra])
        cylinder(d = encoder_shaft_hole_d, h = plate_t + 2 * extra);

}

module quota_windows(extra = 1) {
    // Individual top-panel windows keep each RGB pixel visually separated.
    for (i = [0 : quota_led_count - 1]) {
        translate([
            quota_led_start_x + i * quota_led_pitch - quota_led_window_w / 2,
            quota_led_y - quota_led_window_d / 2,
            -extra
        ])
            cube([
                quota_led_window_w,
                quota_led_window_d,
                plate_t + 2 * extra
            ], center = false);
    }
}

module plate() {
    difference() {
        rounded_prism(case_w, case_d, plate_t, corner_r);
        key_holes();
        screw_holes();
        control_holes();
        quota_windows();
        controller_window();
    }
}

module corner_bosses() {
    // Four integrated M3 bosses receive the upper-lid screws. They are added
    // after hollowing the box so the corner wall remains structurally strong.
    for (p = screw_positions) {
        translate([p[0], p[1], 0])
            difference() {
                cylinder(d = 8, h = bottom_box_h);
                translate([0, 0, -1])
                    cylinder(d = 3.4, h = bottom_box_h + 2);
            }
    }
}

module controller_panel() {
    inner_w = case_w - 2 * bottom_wall_t;
    inner_d = case_d - 2 * bottom_wall_t;
    inner_r = corner_r - bottom_wall_t;
    union() {
        difference() {
            rounded_prism(case_w, case_d, bottom_box_h, corner_r);

            // Hollow the lower panel into a real box while retaining a 2.4 mm
            // floor and side walls. The Type-C opening cuts only the front wall.
            translate([bottom_wall_t, bottom_wall_t, bottom_floor_t])
                rounded_prism(inner_w, inner_d, bottom_box_h, inner_r);
            screw_holes(height = bottom_box_h + 2);
            usb_opening();
        }
        corner_bosses();
        micro_board_shelf();
    }
}

module micro_board_shelf() {
    // Captive cradle for the measured 35 x 18 x 10 mm board. Side rails rise
    // close to the lid so the board cannot slide or lift out after assembly.
    board_x = controller_board_x;
    board_y = controller_board_y;
    pad_x = board_x - controller_board_clearance;
    pad_y = board_y - controller_board_clearance;
    pad_w = controller_board_w + 2 * controller_board_clearance;
    pad_d = controller_board_l + 2 * controller_board_clearance;
    pad_t = 1.2;
    rail_t = 1.4;
    rail_bottom = bottom_floor_t + pad_t - 0.05;
    rail_h = bottom_box_h - 0.6 - rail_bottom;

    translate([pad_x, pad_y, bottom_floor_t - 0.05])
        cube([pad_w, pad_d, pad_t + 0.1], center = false);

    // Long side rails leave 0.6 mm clearance to the board edges.
    translate([pad_x - rail_t, pad_y, rail_bottom])
        cube([rail_t, pad_d, rail_h], center = false);
    translate([pad_x + pad_w, pad_y, rail_bottom])
        cube([rail_t, pad_d, rail_h], center = false);

    // Rear stop prevents the board sliding away from the Type-C port. The
    // front remains open in the middle so the connector has a straight path.
    translate([pad_x - rail_t, pad_y, rail_bottom])
        cube([pad_w + 2 * rail_t, 1.4, 5.0], center = false);
}

module pixel_carrier() {
    // Thin horizontal carrier for 12 individually wired 5 mm-class RGB pixels.
    carrier_w = (quota_led_count - 1) * quota_led_pitch + quota_led_window_w + 4;
    carrier_d = 8;
    carrier_t = 2;
    carrier_x = quota_led_start_x - 2;
    carrier_y = quota_led_y - carrier_d / 2;
    difference() {
        translate([carrier_x, carrier_y, 0])
            rounded_prism(carrier_w, carrier_d, carrier_t, 1.5);
        for (i = [0 : quota_led_count - 1]) {
            translate([
                quota_led_start_x + i * quota_led_pitch - 2.8,
                quota_led_y - 2.8,
                -1
            ])
                cube([5.6, 5.6, carrier_t + 2], center = false);
        }
    }
}

module tolerance_coupon() {
    coupon_w = 70;
    coupon_d = 42;
    difference() {
        rounded_prism(coupon_w, coupon_d, 4, 2);

        // Four switch-hole variants: 13.8, 14.0, 14.2, 14.4 mm.
        for (i = [0 : 3]) {
            translate([9 + i * 17, 21, -1])
                cube([13.8 + i * 0.2, 13.8 + i * 0.2, 6], center = true);
        }

        // M3 insert-hole variants.
        for (i = [0 : 2]) {
            translate([12 + i * 18, 8, -1])
                cylinder(d = 4.0 + i * 0.2, h = 6);
        }
    }
}

module assembly() {
    color("#d8d8d8")
        translate([0, 0, bottom_box_h])
            plate();
    color("#666666")
        controller_panel();
    color("#555555")
        translate([0, 0, bottom_box_h - 2])
            pixel_carrier();
}
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

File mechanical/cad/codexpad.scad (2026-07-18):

// CodexPad / 13keyAgentTools Rev 0.1
// Parametric first-pass enclosure for a hand-wired Arduino Micro macro pad.
// Export one part at a time by changing `part`.

part = "plate"; // plate / bottom / assembly / tolerance

$fn = 48;

case_w = 148;
case_d = 106;
plate_t = 3.0;
bottom_h = 18.0;
bottom_t = 3.0;
wall = 3.0;
corner_r = 4.0;

key_pitch = 19.05;
key_hole = 14.0;
key_origin = [22, 15];

// 4 x 4 electrical matrix with three unused positions.
// Rev 0.1 uses 13 individual 1U keys. A 2U visual key can be added later.
key_positions = [
    [0, 0], [1, 0], [2, 0], [3, 0],
    [0, 1], [1, 1], [2, 1], [3, 1],
    [0, 2], [1, 2], [2, 2], [3, 2],
    [1, 3]
];

screw_positions = [
    [7, 7],
    [case_w - 7, 7],
    [7, case_d - 7],
    [case_w - 7, case_d - 7]
];

module rounded_prism(w, d, h, r) {
    linear_extrude(height = h)
        offset(r = r)
            offset(delta = -r)
                square([w, d], center = false);
}

module key_holes(extra = 1) {
    for (p = key_positions) {
        translate([
            key_origin[0] + p[0] * key_pitch,
            key_origin[1] + p[1] * key_pitch,
            -extra
        ])
            cube([key_hole, key_hole, plate_t + 2 * extra], center = false);
    }
}

module screw_holes(extra = 1) {
    for (p = screw_positions) {
        translate([p[0], p[1], -extra])
            cylinder(d = 3.4, h = plate_t + bottom_h + 2 * extra);
    }
}

module control_holes(extra = 1) {
    // EC11 shaft and anti-rotation clearance.
    translate([113, 86, -extra])
        cylinder(d = 8.0, h = plate_t + 2 * extra);
    translate([113, 78, -extra])
        cube([12, 16, plate_t + 2 * extra], center = true);

    // Generic 2-axis joystick keep-out. Tune after buying the actual module.
    translate([133, 86, -extra])
        cube([19, 19, plate_t + 2 * extra], center = true);

    // TTP223 copper touch window.
    translate([94, 86, -extra])
        cube([14, 14, plate_t + 2 * extra], center = true);

    // Rear USB opening. This is intentionally oversized for cable tolerance.
    translate([case_w / 2 - 9, case_d - 4, -extra])
        cube([18, 8, 9], center = false);
}

module plate() {
    difference() {
        rounded_prism(case_w, case_d, plate_t, corner_r);
        key_holes();
        screw_holes();
        control_holes();
    }
}

module bottom() {
    difference() {
        rounded_prism(case_w, case_d, bottom_h, corner_r);

        // Main cavity. Keep a solid bottom and a perimeter wall.
        translate([wall, wall, bottom_t])
            cube([
                case_w - 2 * wall,
                case_d - 2 * wall,
                bottom_h
            ], center = false);

        // Through holes for M3 hardware.
        for (p = screw_positions) {
            translate([p[0], p[1], -1])
                cylinder(d = 3.4, h = bottom_h + 2);
        }

        // Rear cable relief.
        translate([case_w / 2 - 10, case_d - 5, 4])
            cube([20, 8, 10], center = false);
    }
}

module tolerance_coupon() {
    coupon_w = 70;
    coupon_d = 42;
    difference() {
        rounded_prism(coupon_w, coupon_d, 4, 2);

        // Four switch-hole variants: 13.8, 14.0, 14.2, 14.4 mm.
        for (i = [0 : 3]) {
            translate([9 + i * 17, 21, -1])
                cube([13.8 + i * 0.2, 13.8 + i * 0.2, 6], center = true);
        }

        // M3 insert-hole variants.
        for (i = [0 : 2]) {
            translate([12 + i * 18, 8, -1])
                cylinder(d = 4.0 + i * 0.2, h = 6);
        }
    }
}

module assembly() {
    color("#d8d8d8")
        translate([0, 0, bottom_h])
            plate();
    color("#666666")
        bottom();
}

if (part == "plate") {
    plate();
} else if (part == "bottom") {
    bottom();
} else if (part == "assembly") {
    assembly();
} else if (part == "tolerance") {
    tolerance_coupon();
}

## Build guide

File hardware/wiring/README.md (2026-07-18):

# Arduino Micro 手焊接线

## 结构

13 个按键采用 4×4 电气矩阵，其中 3 个位置空着；面板物理布局为左上 1 键加下方 4×3。每个按键串联一个 1N4148 二极管，方向统一使用 QMK 的 `COL2ROW` 约定。Rev 0.7 使用一个带按压开关的 EC11，预留给未来音量控制。

QMK 手焊指南对矩阵、二极管和 Pro Micro 控制板有完整说明：<https://docs.qmk.fm/hand_wire>。

## 连接原则

- 按键矩阵的 4 行连接 Arduino Micro 的 D4～D7。
- 按键矩阵的 4 列连接 D8～D11。
- 矩阵二极管的黑色环方向必须统一。
- 音量 EC11 的 A/B/按压分别连接 D2/D3/D12。
- 12 颗独立 quota RGB 灯的 DIN 接 A3，VCC 接 5V，GND 接 GND；DIN 方向从控制器侧进入第 0 颗灯。
- 12 颗灯沿键盘面板窗口逐颗排列，左侧为第 0 灯，右侧为第 11 灯；也可使用裁切后的 12 像素 RGB 灯带。
- 在 DIN 串联约 330 Ω 电阻，并在灯带电源入口并联 1000 µF 以上电解电容。

## 手焊安全

- 焊接、改线和测量电阻时拔掉 USB。
- 第一次上电只连接 Arduino Micro，不连接 RGB。
- 不要把 12 颗 RGB 灯全白满亮度直接从 USB 长时间供电；首版建议亮度不超过 20～30%。
- 先用万用表确认 5V 与 GND 没有短路。
- USB-C 插口要在外壳上做支撑，避免主控板 USB-C 焊盘受力。

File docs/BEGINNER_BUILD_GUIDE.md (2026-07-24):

# Rev 0.9.4 从 0 到 1 手焊装配说明书

这份说明书按“**没有定制 PCB，直接把元件焊到导线上**”的路线编写，适合第一次焊接键盘的人。现在全部硬件已经到齐，按下面的总图从上层面板、主控板、RGB 灯带到最终合盖依次完成。

## 先看装配视频

[播放/下载：Rev 0.9.4 封闭盒体装配视频](media/assembly_walkthrough.mp4)

## 先看这张完整总图

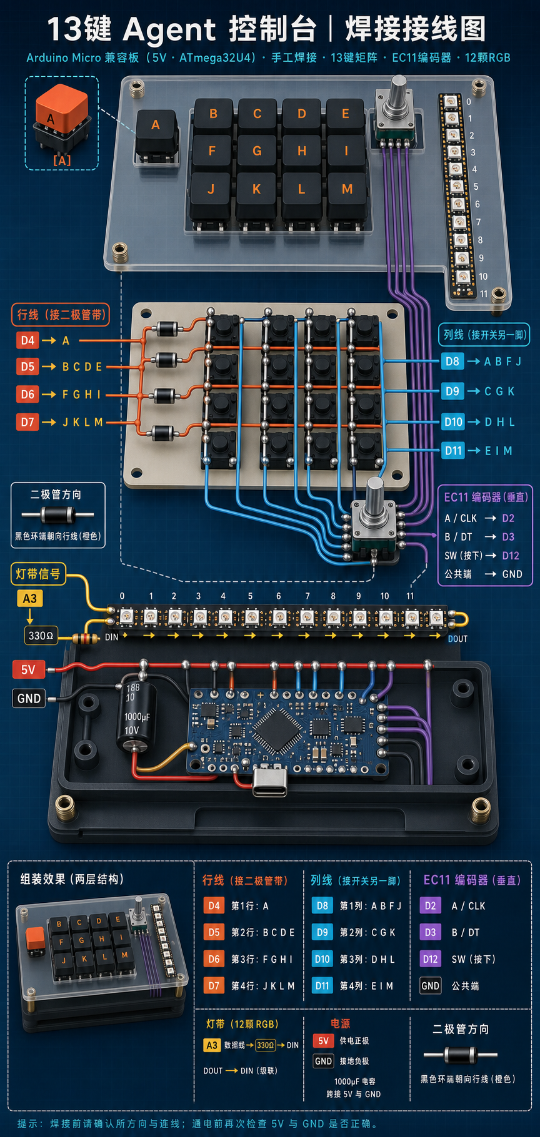
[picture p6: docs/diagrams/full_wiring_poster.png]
参考风格完整焊接接线图


按图中的顺序做：

1. ① 把上层面板翻到背面，焊 13 个按键、13 个二极管和 EC11。
2. ② 把 Arduino Micro 卡入下层封闭盒体，再接 D4–D11、D2、D3、D12 和 GND。
3. ③ 最后接 12 颗 RGB：A3→330Ω→DIN，5V/GND 并联。
4. ④ 开盖通电测试，全部正常后再合上上下层面板。

**第一次通电前必须用万用表确认 5V 和 GND 没有短路。**

## 按键面板背面细节

面板背面实物焊接示意

把面板翻到背面，看到黑色按键和两个银色针脚；黄色小元件是二极管。每个按键左边接二极管，二极管黑环朝橙色行线，按键右边接蓝色列线。

如果只想照着最短步骤做：

1. 先装好 13 个按键。
2. 每个按键左边焊一只二极管，黑环朝橙色行线。
3. 按图把右边针脚接到蓝色列线。
4. 每根橙色/蓝色总线留 10–15cm，贴上 D4、D5、D6、D7、D8、D9、D10、D11 标签。
5. 用万用表检查，再把 8 根矩阵线接到 Arduino。

### B 键的具体焊点

如果你现在正在焊 B 键，只看下面这张图：

B 键三个焊点的实物位置示意

B 键有三个相关焊点，但**不是三个东西焊在同一个焊点上**：

- B 左针脚：焊二极管的一端。
- 二极管黑环端：焊 D5 橙色行线。
- B 右针脚：只焊 D8 蓝色列线。

### B、C、D、E 的橙色行线

BCDE 共用 D5 行线

是的，B、C、D、E 属于同一行，所以把**四个二极管的黑环端**用一根橙色线连起来，这根线最后标记为 `D5`。不要把 B、C、D、E 的按键针脚直接互相连接。

## 先记住这一点：你的按键只有 2 个针脚

按键的两个针脚就是一个普通开关，**没有正负极，左右两脚可以互换**。每个按键还要另外串联一只 1N4148 二极管；二极管不是按键的第三个针脚，黑色环方向才有正负之分。

两针按键和二极管焊接示意

本项目的目标连接关系是：

```text
列线 D8/D9/D10/D11 ── 按键（两脚任意一侧） ── 二极管 ── 行线 D4/D5/D6/D7
                                                        ↑
                                             二极管黑环朝行线
```

## 你现在要准备的东西

### 已有的硬件

- 13 个两针机械按键和 13 个 1N4148 二极管
- 1 个照片中的立式 EC11 旋转编码器，轴径 6mm
- 3D 打印的 `plate.stl`、`bottom.stl`、`pixel_carrier.stl` 和封闭用 `window_lens.stl`
- 26–30 AWG 软导线、M3 螺丝/支柱、旋钮帽、键帽

### 其他硬件

- Arduino Micro 兼容主控板：ATmega32U4、5V、16MHz、USB-C
- 5V 可寻址 WS2812B/SK6812 RGB 灯带或 12 颗独立 RGB 灯

### 工具和安全用品

- 可调温电烙铁、烙铁架、黄铜棉或湿海绵
- 细焊锡、助焊剂、斜口钳、尖嘴钳、剥线钳
- 万用表，最好有“二极管测试”档
- 热缩管或绝缘胶带、标签纸/记号笔、镊子
- 护目镜和通风设备

推荐温度：含铅焊锡约 320–340°C；无铅焊锡约 350–370°C。焊接时不要连接 USB-C，也不要让烙铁碰到 PLA/PETG 面板。

## 总体装配顺序

封闭盒体与主板卡槽装配关系

按下面顺序做，每一步完成后都先检查，不要一次把所有线焊完：

1. 试装 3D 打印件和 13 个按键。
2. 练习两个焊点，熟悉烙铁。
3. 安装按键，给每个按键串联二极管。
4. 连接 4 根行线和 4 根列线，留下带标签的线尾。
5. 用万用表检查每个按键、二极管方向和短路情况。
6. 安装并焊接立式 EC11。
7. Arduino Micro 先用临时线连接并上传固件，再永久整理线束。
8. 最后接 RGB 灯带、电阻和电容。
9. 安装透明窗片，合上上层控制盖，完成最终测试。

## 第 1 步：打印件试装

1. 先打印 `tolerance_coupon.stl`，验证按键孔、6mm 旋钮轴孔和 M3 热熔螺母。
2. 打印 `plate.stl`。从上面看，13 个按键是左上 1 个加下面 4×3 个。
3. 把 13 个按键逐个从面板上方压入，不要用烙铁加热按键孔。
4. 把 EC11 从面板下方放入，6mm 轴穿过面板的约 Ø6.2mm 圆孔。旋钮本体留在面板下方，只有轴和旋钮帽在上方。
5. 旋钮轴如果略紧，只用圆锉或细砂纸轻微扩大；不要把圆孔改成长方孔。
6. 将 35×18×10 mm Arduino Micro 放入 `bottom.stl` 的卡槽：先让后端贴住后挡块，再向下压入左右导轨；确认 USB-C 插座落在前墙开口中心。
7. 不要把导线压进卡槽；主板两侧与导轨约有 0.6 mm 间隙，焊点和元件不能顶住导轨。

不要在这一步粘胶。先确认所有零件都能拆下来，后面还要翻到面板背面焊接。

## 第 2 步：先学会一个漂亮焊点

拿一只二极管和一小段废线练习：

1. 烙铁头擦干净并上少量锡。
2. 用尖嘴钳把元件脚或导线固定在焊盘上。
3. 烙铁头同时碰到焊盘和针脚约 1–2 秒。
4. 从烙铁另一侧送入少量焊锡，让焊锡同时润湿焊盘和针脚。
5. 先移开焊锡，再移开烙铁，等 2 秒自然冷却。
6. 合格焊点应像小火山或小圆锥，表面光亮；不要像一颗悬空的焊锡球。

### 三种常见错误

| 现象 | 原因 | 修复 |
|---|---|---|
| 焊锡成球、不粘焊盘 | 焊盘没有被加热或表面有油污 | 加一点助焊剂，再同时加热焊盘和针脚 |
| 焊点灰暗、粗糙 | 冷焊点 | 重新加热至焊锡完全融化，必要时补少量新锡 |
| 两个焊点连成一坨 | 锡太多或线头太长 | 断电后用吸锡带/吸锡器清掉，再重新焊 |

## 第 3 步：安装 13 个两针按键

1. 把上层面板翻到正面，按键从正面压入。
2. 让所有按键方向一致。这样翻到背面后，每个按键的同一侧针脚都可作为“列侧”。
3. 按照下面的编号贴小标签，避免后面焊错。

```text
[ A ][ --][ --][ --]
[ B ][ C ][ D ][ E ]
[ F ][ G ][ H ][ I ]
[ J ][ K ][ L ][ M ]
```

这就是当前 CAD 面板的实际布局：左上单键 A，下面 4×3。为了不混淆，建议直接在按键背面写上 A–M。

注意：按键两脚不分正负，关键是**每个按键必须有一只独立二极管**，并且二极管方向全部一致。

## 第 4 步：焊二极管和按键矩阵

### 4.1 先只完成 A 键

不要一上来焊 13 个。先完成 A：

1. 选定 A 按键的一侧针脚作为列侧，焊一根线，在线尾贴 `COL0 / D8`。
2. A 按键另一侧针脚接 1N4148 二极管的一端。
3. 二极管黑色环的一端接行侧，焊一根线，在线尾贴 `ROW0 / D4`。
4. 用万用表检查线没有脱落，再照这个方法复制到其他按键。

二极管的黑色环是阴极，方向如下：

```text
列侧 ── 按键 ── 二极管无黑环端  |黑环|  ── 行侧
D8/D9/D10/D11                              D4/D5/D6/D7
```

### 4.2 4 根行线和 4 根列线

13 键矩阵焊接示意

推荐用橙色线做行线、蓝色线做列线，并让每根总线最后只留下 1 根接主控板的线尾。每根线尾留 10–15cm，末端用热缩管或标签标注。

| 主控脚位 | 行线包含的按键 | 备注 |
|---|---|---|
| D4 | A | Row 0，二极管黑环接这里 |
| D5 | B、C、D、E | Row 1，二极管黑环接这里 |
| D6 | F、G、H、I | Row 2，二极管黑环接这里 |
| D7 | J、K、L、M | Row 3，二极管黑环接这里 |

| 主控脚位 | 列线包含的按键 |
|---|---|
| D8 | A、B、F、J |
| D9 | C、G、K |
| D10 | D、H、L |
| D11 | E、I、M |

三处空位不装按键，也不接线。行线必须接二极管的黑环一侧；列线接按键的另一侧。

### 4.3 线怎么焊才不容易乱

- 先焊所有二极管，再焊行线，最后焊列线。
- 每完成一组就拍照，照片里要能看到标签和焊点。
- 导线剥皮 3–4mm，焊点外不要留很长的裸铜丝。
- 线跨过另一组总线时，用热缩管隔离；不要让裸线交叉接触。
- 不要把行线和列线焊成一个大网。每一个交点都要看清楚是否有绝缘。
- 还没有主控板时，不要把行列线接到 5V、GND 或 USB 外壳。

## 第 5 步：不用主控板也能完成的万用表检查

检查时 USB 必须拔掉，面板上也不能连接任何电源。

### 5.1 外观检查

- [ ] 13 个按键都牢固，没有松动或被面板卡住。
- [ ] 13 个二极管都存在，黑环方向统一。
- [ ] D4–D7 四根行线有标签，D8–D11 四根列线有标签。
- [ ] 没有焊锡桥，没有露出的长线头。
- [ ] 6mm 旋钮轴能自由转动，不碰面板孔边。

### 5.2 每个按键逐个测

把万用表拨到二极管测试档。以 A 键为例：

1. 按住 A 键。
2. 红表笔接 A 的列侧（D8），黑表笔接 A 的行侧（D4，二极管黑环一侧）。
3. 应看到约 0.5–0.8V 的二极管压降。
4. 松开 A 键，读数应恢复为断路/OL。
5. 交换红黑表笔，应该是断路/OL；若反向也导通，二极管方向或焊接可能错误。

依次检查 A–M。若某键两边都 OL，优先检查按键脚、二极管脚和该键的线尾；若两边都接近 0V，优先检查焊锡桥。

### 5.3 总线检查

- D4、D5、D6、D7 之间应互不导通。
- D8、D9、D10、D11 之间应互不导通。
- 未按键时，任意行列组合不应出现低阻短路。
- 按下某键时，只允许它对应的行列组合出现二极管压降。

这一步通过后，键盘面板的核心焊接已经完成。即使主控板晚几天到，也不要急着接电测试。

## 第 6 步：安装立式 EC11 旋钮

当前模型适配的是照片中的**立式/垂直轴 EC11**，不是卧式、侧插型编码器。面板孔是圆形约 Ø6.2mm，用来给 6mm 轴预留 FDM 打印间隙。

EC11 和 RGB 灯接线示意

### 6.1 机械安装

1. 从面板下方放入 EC11，本体贴在面板背面。
2. 让 6mm 轴从面板圆孔伸出。
3. 先装旋钮帽，确认旋转不刮擦面板；不要用过大的旋钮帽硬压轴。
4. EC11 本体用短线焊接，线长以能翻开面板维修为准，不要拉紧。

### 6.2 电气接线

EC11 不同厂家针脚顺序可能不同，不能只看外观猜。常见 5 脚逻辑如下：

| EC11 功能 | Arduino Micro |
|---|---|
| A / CLK | D2 |
| B / DT | D3 |
| C / COM | GND |
| SW1 | D12 |
| SW2 | GND |

无主控板时，用万用表找脚：旋转时 A/C、B/C 会交替通断；按下时 SW1/SW2 才通断。找到后给五根线分别贴 `ENC_A`、`ENC_B`、`ENC_GND`、`ENC_SW`、`ENC_SW_GND`。

不要把 EC11 的公共脚直接接 5V。固件使用 Arduino 的 `INPUT_PULLUP`，按上表接线。

## 第 7 步：接 RGB 灯带

接灯带前先确认它是 5V 可寻址型号，然后：

1. 将 12 颗灯放入 `pixel_carrier.stl`，确认正面朝向面板窗口。
2. 先只接第 0 颗灯、330Ω 电阻、5V 和 GND。
3. 单颗测试通过后，再串接其余 11 颗。

到货后必须确认是 **5V 可寻址** WS2812B/SK6812；普通 12V RGB 灯带或只有四根模拟 RGB 线的灯带不能直接使用当前固件。接线关系是：

```text
A3 ── 330Ω ── DIN [灯0] DOUT ── DIN [灯1] DOUT ── … ── [灯11]
5V ─────────────────────── 并联到每一颗灯的 5V
GND ────────────────────── 并联到每一颗灯的 GND
```

在灯带电源入口并联 1000µF 电解电容：电容正极接 5V，负极接 GND。灯带箭头必须从 Arduino A3 指向灯 0，再指向灯 1；方向反了会全不亮。

## 第 8 步：全部硬件到齐后的第一次通电

### 8.1 先临时接线，不要马上永久焊

先用杜邦线或临时焊线连接，不要立即合上外壳：

```text
ROW0 D4    ROW1 D5    ROW2 D6    ROW3 D7
COL0 D8    COL1 D9    COL2 D10   COL3 D11
EC11 A D2  EC11 B D3  EC11 SW D12
所有 GND 共地；第一次测试按键和旋钮时，RGB 暂时不接，`ENABLE_RGB` 保持 0
```

1. 目测主控板没有桥接或弯针。
2. 万用表测主控板 5V 与 GND，不应短路。
3. 只连接 USB-C，确认电脑识别 Arduino Micro。
4. Arduino IDE 选择 `Tools > Board > Arduino Micro`。
5. 先上传 Blink，再上传 `firmware/arduino/agent_macro_mvp/agent_macro_mvp.ino`。
6. 在空白文本框中逐个按 A–M，确认没有漏键或串键。
7. 旋转 EC11，确认方向；方向反了就交换 D2/D3 两根线。

如果上传时端口消失，快速按两次 Reset，再选择 Bootloader 串口。USB-C 线必须是数据线，不是只有充电的线。

当前固件的默认动作是：A=Enter，B=Esc，C=Ctrl+N，D=Ctrl+Shift+D，E–M=F1–F9；这是通用宏占位，后续可按 Codex、Claude、Qoder 的实际快捷键修改。

## 第 9 步：RGB 到货后的测试顺序

1. 先只接 1 颗 RGB 灯、330Ω 电阻和 5V/GND。
2. `ENABLE_RGB` 改为 `1`，安装 Arduino IDE 的 Adafruit NeoPixel 库并上传。
3. 先用 20–30% 亮度测试，不要一开始全白满亮度。
4. 单颗正常后，再接完 12 颗，确认 DIN/DOUT 方向和共地。
5. 最后用主机工具测试：

   ```bash
   python host/agentd/agentd.py --list
   python host/agentd/agentd.py --port /dev/cu.usbmodemXXXX --quota 50
   ```

Windows 下串口通常是 `COM3` 这类名称。USB 供电时，如果 12 灯点亮导致主控重启，先降低亮度，检查电容和电源线，不要继续满亮度运行。

## 第 10 步：最终机械装配

最终封闭盒体装配关系

1. 拔掉 USB-C。
2. Arduino Micro 卡入 `bottom.stl` 的 35×18×10 mm 主控卡槽，USB-C 对准下层盒体前墙开口。
3. 将 RGB 灯和导线固定在 `pixel_carrier.stl`，确保灯珠正面朝向面板窗口。
4. 整理矩阵和 EC11 线束，所有裸露焊点加热缩管或绝缘胶带。
5. 从下方将 `window_lens.stl` 或同尺寸透明亚克力片压到主板观察窗边缘；这一步是封闭主板的必要步骤。
6. 用四个 M3×16mm 螺丝锁入下层盒体四角固定柱，先松装，确认线束没有被夹住。
7. 插拔一次 USB-C，确认插头不会顶住外壳，之后再均匀拧紧四角螺丝。
8. 贴防滑脚垫，完成最终测试。

## 出现问题时按这个顺序排查

| 现象 | 先检查 |
|---|---|
| 某一个按键不响应 | 按键两脚是否有焊点、二极管黑环是否朝行线、该键线尾是否断 |
| 一整行不响应 | D4–D7 对应行线是否断路，是否把二极管黑环焊到了列线 |
| 一整列不响应 | D8–D11 对应列线是否断路，列线是否焊到按键同一侧 |
| 多个键一起误触 | 行列之间有锡桥、裸线交叉短路，或二极管方向不统一 |
| EC11 方向反了 | 交换 A/B 两根线；不要交换公共 GND |
| USB 完全不识别 | USB-C 是否为数据线、主控是否为 ATmega32U4 5V/16MHz、双击 Reset |
| RGB 全不亮 | `ENABLE_RGB`、5V/GND 极性、A3 到 DIN、电阻位置、箭头方向 |
| RGB 一亮就重启 | 降低亮度、接 1000µF 电容、检查 5V/GND 和 USB 供电余量 |

## 完成标准

- [ ] 13 个两针按键全部安装，按键本身没有极性。
- [ ] 13 个 1N4148 二极管全部串联，黑环统一朝 D4–D7 行线。
- [ ] 4 根行线和 4 根列线都贴有明确标签。
- [ ] 万用表逐键测到正确的单向二极管压降。
- [ ] 立式 EC11 6mm 轴穿过约 Ø6.2mm 圆孔，旋转和按压不刮面板。
- [ ] 主控板到货后先在未合盖状态测试，再进行最终装配。
- [ ] 主控板完全落入 35×18×10 mm 卡槽，Type-C 插口由盒体前墙承受插拔力。
- [ ] RGB 灯带确认是 5V 可寻址型号，并按 DIN→DOUT 方向连接。

相关资料：[引脚表](../hardware/wiring/pinout.md)、[硬件测试计划](../hardware/test-plan.md)、[采购清单](../hardware/purchase-list.md)、[打印计划](../mechanical/print/PRINT_PLAN.md)。

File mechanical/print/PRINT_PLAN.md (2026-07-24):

# 打印计划

## Bambu Studio 快速开始

当前 Rev 0.9.4 可打印文件：

装配过程可先看：[Rev 0.9.4 封闭盒体装配视频](../../docs/media/assembly_walkthrough.mp4)

- `../exports/tolerance_coupon.stl`：先打印，用来确定轴孔和 M3 热熔螺母公差。
- `../exports/pixel_carrier.stl`：12 颗独立 RGB 灯珠的定位承载条。
- `../exports/plate.stl`：上层控制盖，包含 13 键、旋钮、水平灯窗和主板透明窗。
- `../exports/bottom.stl`：封闭下层盒体，包含 35×18×10 mm 主控卡槽、侧向导轨、后挡块和前墙 Type-C 插口。
- `../exports/window_lens.stl`：封闭主板观察窗的透明 PETG 镜片；如有条件，优先用同尺寸透明亚克力片替代。

将 STL 拖入 Bambu Studio 后，先按实际材料选择 PLA 或 PETG 配置，再切片预览。下层盒体底面朝打印床，上层控制盖外观面朝上；透明窗必须安装后再合盖。四角使用 M3 螺丝锁入下层盒体的打印柱。灯珠承载条建议用普通 PLA/PETG；如果需要更柔和的光线，可在面板孔上方增加半透明薄片。当前文件只包含几何模型，不包含机器专用的 3MF 工程、耗材配置或 G-code。

建议首轮参数：0.4 mm 喷嘴、0.20 mm 层高、3 道墙、15～25% 填充；定位板、灯珠承载条和公差件平放打印，底壳底面朝打印床。

## 第 1 批：公差件

在 `mechanical/cad/agent_macro.scad` 中设置：

```scad
part = "tolerance";
```

打印后测试：

- 轴体能否插入和拔出
- 键帽是否会顶住定位板
- EC11 轴杆和旋钮孔是否同心
- M3 铜螺母孔是否过松或过紧

## 第 2 批：封闭盒底和上层控制盖

```scad
part = "plate";
part = "bottom";
```

推荐初始切片参数：

- 材料：PLA 或 PETG
- 喷嘴：0.4 mm
- 层高：0.16～0.20 mm
- 墙数：3
- 顶底层：4
- 填充：15～25%
- 上层控制盖平放、外观面朝上；下层盒体底面朝打印床

## 验收

- 上盖不翘曲
- 13 个轴体均能垂直安装
- 35×18×10 mm Arduino Micro 能完全落入卡槽，左右无明显晃动，侧向导轨不压住元件
- USB-C 插座与下层盒体前墙 14×9 mm 开口对齐，插头可顺畅插拔且不让主板焊盘受力
- 25.4×51.4×1.5 mm 透明窗片从下方覆盖 24×50 mm 窗口，合盖后主板不外露
- 实际 EC11 的 6 mm 轴能顺畅通过约 6.2 mm 圆孔，旋钮轴不被面板卡住
- 上层控制盖与下层盒体四角柱贴合，M3 螺丝不顶住按键和焊点
- 盒内线束不进入主控卡槽，主板侧边导轨和后挡块能稳定限位
- EC11 旋钮操作不干涉
- 上层面板水平 12 个灯窗与独立 RGB 灯像素位置对齐

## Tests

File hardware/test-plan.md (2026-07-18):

# 硬件测试计划

## H0：板卡上电

- [ ] 视觉检查焊点，没有桥接
- [ ] USB 5V 与 GND 之间没有短路
- [ ] Arduino Micro 能被电脑识别
- [ ] Reset 后能重新进入 Bootloader

## H1：矩阵

- [ ] 13 个按键逐个触发
- [ ] 同一行同时按两个键没有误触
- [ ] 同一列同时按两个键没有误触
- [ ] 三个空位不会产生虚假按键

## H2：控制器

- [ ] 音量 EC11 顺时针/逆时针方向正确
- [ ] 音量 EC11 按压动作正确

## H3：灯光和电源

- [ ] 单颗 RGB 正确显示
- [ ] 12 颗独立 RGB quota 灯在 20～30% 亮度下稳定
- [ ] `QUOTA 0` 时灯带全灭
- [ ] `QUOTA 50` 时约一半灯亮
- [ ] `QUOTA 100` 时 12 灯全亮
- [ ] `QUOTA 42` 时中间像素有部分亮度，颜色过渡平滑
- [ ] USB 长时间连接不掉线
- [ ] RGB 断电时键盘输入仍可用

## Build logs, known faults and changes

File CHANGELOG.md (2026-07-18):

# Changelog

## Unreleased

- 建立 13 键 Agent 控制器独立工程。
- 增加 OpenSCAD 参数化外壳、定位板和公差件。
- 增加 Arduino Micro 手焊接线、BOM、MVP 固件和 USB CDC 测试工具。
- 增加工程迭代记录和 GitHub Actions 基础检查。

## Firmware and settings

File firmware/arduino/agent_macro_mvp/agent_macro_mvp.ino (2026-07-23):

// 13keyAgentTools Rev 0.5
// Arduino Micro MVP firmware for a multi-agent macro keyboard.

#include <Keyboard.h>
#include <stdio.h>
#include <string.h>

// Set to 1 after installing Adafruit NeoPixel and wiring the 12-pixel quota bar.
#ifndef ENABLE_RGB
#define ENABLE_RGB 0
#endif

#if ENABLE_RGB
#include <Adafruit_NeoPixel.h>
#define RGB_COUNT 12
Adafruit_NeoPixel pixels(RGB_COUNT, A3, NEO_GRB + NEO_KHZ800);
#endif

const uint8_t ROW_COUNT = 4;
const uint8_t COL_COUNT = 4;
const uint8_t rowPins[ROW_COUNT] = {4, 5, 6, 7};
const uint8_t colPins[COL_COUNT] = {8, 9, 10, 11};

const uint8_t encoderA = 2;
const uint8_t encoderB = 3;
const uint8_t encoderSwitch = 12;

const uint32_t debounceMs = 25;

enum Action : uint8_t {
  ACTION_NONE = 0,
  ACTION_ACCEPT,
  ACTION_REJECT,
  ACTION_NEW_CHAT,
  ACTION_PUSH_TO_TALK,
  ACTION_FUNCTION_1,
  ACTION_FUNCTION_2,
  ACTION_FUNCTION_3,
  ACTION_FUNCTION_4,
  ACTION_FUNCTION_5,
  ACTION_FUNCTION_6,
  ACTION_FUNCTION_7,
  ACTION_FUNCTION_8,
  ACTION_FUNCTION_9,
  ACTION_LAYER,
};

// 4x4 matrix; three positions are intentionally unused.
const Action actions[ROW_COUNT][COL_COUNT] = {
  {ACTION_ACCEPT, ACTION_NONE, ACTION_NONE, ACTION_NONE},
  {ACTION_REJECT, ACTION_NEW_CHAT, ACTION_PUSH_TO_TALK, ACTION_FUNCTION_1},
  {ACTION_FUNCTION_2, ACTION_FUNCTION_3, ACTION_FUNCTION_4, ACTION_FUNCTION_5},
  {ACTION_FUNCTION_6, ACTION_FUNCTION_7, ACTION_FUNCTION_8, ACTION_FUNCTION_9},
};

bool matrixStable[ROW_COUNT][COL_COUNT] = {};
uint32_t matrixChangedAt[ROW_COUNT][COL_COUNT] = {};

uint8_t lastEncoderState = 0;
bool lastEncoderSwitch = HIGH;

void tapKey(uint8_t key) {
  Keyboard.press(key);
  delay(8);
  Keyboard.release(key);
}

void sendCombo(uint8_t modifier, uint8_t key) {
  Keyboard.press(modifier);
  Keyboard.press(key);
  delay(8);
  Keyboard.release(key);
  Keyboard.release(modifier);
}

void sendFunction(uint8_t functionNumber) {
  // Arduino Keyboard defines KEY_F1..KEY_F12. Keep function keys as
  // Temporary host-side workflow hooks until per-agent shortcuts are configured.
  switch (functionNumber) {
    case 1: tapKey(KEY_F1); break;
    case 2: tapKey(KEY_F2); break;
    case 3: tapKey(KEY_F3); break;
    case 4: tapKey(KEY_F4); break;
    case 5: tapKey(KEY_F5); break;
    case 6: tapKey(KEY_F6); break;
    case 7: tapKey(KEY_F7); break;
    case 8: tapKey(KEY_F8); break;
    case 9: tapKey(KEY_F9); break;
    case 10: tapKey(KEY_F10); break;
    case 11: tapKey(KEY_F11); break;
    case 12: tapKey(KEY_F12); break;
    default: break;
  }
}

void emitAction(Action action) {
  switch (action) {
    case ACTION_ACCEPT:
      tapKey(KEY_RETURN);
      break;
    case ACTION_REJECT:
      tapKey(KEY_ESC);
      break;
    case ACTION_NEW_CHAT:
      sendCombo(KEY_LEFT_CTRL, 'n');
      break;
    case ACTION_PUSH_TO_TALK:
      Keyboard.press(KEY_LEFT_CTRL);
      Keyboard.press(KEY_LEFT_SHIFT);
      Keyboard.press('d');
      delay(8);
      Keyboard.release('d');
      Keyboard.release(KEY_LEFT_SHIFT);
      Keyboard.release(KEY_LEFT_CTRL);
      break;
    case ACTION_FUNCTION_1: sendFunction(1); break;
    case ACTION_FUNCTION_2: sendFunction(2); break;
    case ACTION_FUNCTION_3: sendFunction(3); break;
    case ACTION_FUNCTION_4: sendFunction(4); break;
    case ACTION_FUNCTION_5: sendFunction(5); break;
    case ACTION_FUNCTION_6: sendFunction(6); break;
    case ACTION_FUNCTION_7: sendFunction(7); break;
    case ACTION_FUNCTION_8: sendFunction(8); break;
    case ACTION_FUNCTION_9: sendFunction(9); break;
    case ACTION_LAYER: sendFunction(10); break;
    case ACTION_NONE: break;
  }
}

void setupMatrix() {
  for (uint8_t row = 0; row < ROW_COUNT; row++) {
    pinMode(rowPins[row], OUTPUT);
    digitalWrite(rowPins[row], HIGH);
  }
  for (uint8_t col = 0; col < COL_COUNT; col++) {
    pinMode(colPins[col], INPUT_PULLUP);
  }
}

void scanMatrix() {
  const uint32_t now = millis();

  for (uint8_t row = 0; row < ROW_COUNT; row++) {
    for (uint8_t other = 0; other < ROW_COUNT; other++) {
      digitalWrite(rowPins[other], HIGH);
    }
    digitalWrite(rowPins[row], LOW);
    delayMicroseconds(30);

    for (uint8_t col = 0; col < COL_COUNT; col++) {
      const bool pressed = digitalRead(colPins[col]) == LOW;
      if (pressed != matrixStable[row][col]) {
        if (now - matrixChangedAt[row][col] >= debounceMs) {
          matrixStable[row][col] = pressed;
          if (pressed) {
            emitAction(actions[row][col]);
          }
        }
      } else {
        matrixChangedAt[row][col] = now;
      }
    }
  }
  digitalWrite(rowPins[0], HIGH);
}

void scanEncoder() {
  const uint8_t currentState = (digitalRead(encoderA) << 1) | digitalRead(encoderB);
  if (currentState != lastEncoderState) {
    const bool clockwise =
      (lastEncoderState == 0 && currentState == 1) ||
      (lastEncoderState == 1 && currentState == 3) ||
      (lastEncoderState == 3 && currentState == 2) ||
      (lastEncoderState == 2 && currentState == 0);
    sendFunction(clockwise ? 12 : 11);
    lastEncoderState = currentState;
  }

  const bool currentSwitch = digitalRead(encoderSwitch);
  if (currentSwitch != lastEncoderSwitch) {
    delay(3);
    if (digitalRead(encoderSwitch) == LOW) {
      sendFunction(10);
    }
    lastEncoderSwitch = currentSwitch;
  }
}

void setRgb(uint8_t index, uint8_t red, uint8_t green, uint8_t blue) {
#if ENABLE_RGB
  if (index >= RGB_COUNT) {
    return;
  }
  pixels.setPixelColor(index, pixels.Color(red, green, blue));
  pixels.show();
#else
  (void)index;
  (void)red;
  (void)green;
  (void)blue;
#endif
}

void clearRgb() {
#if ENABLE_RGB
  pixels.clear();
  pixels.show();
#endif
}

void setQuotaPercent(uint8_t percent) {
#if ENABLE_RGB
  const uint8_t clamped = percent > 100 ? 100 : percent;
  const uint16_t scaled = static_cast<uint16_t>(clamped) * RGB_COUNT;
  const uint8_t fullPixels = scaled / 100;
  const uint8_t partialPercent = scaled % 100;
  uint8_t red = 220;
  uint8_t green = 220;
  const uint8_t blue = 0;
  if (clamped <= 50) {
    green = (static_cast<uint16_t>(clamped) * 220) / 50;
  } else {
    red = (static_cast<uint16_t>(100 - clamped) * 220) / 50;
  }

  for (uint8_t index = 0; index < RGB_COUNT; index++) {
    if (index < fullPixels) {
      pixels.setPixelColor(index, pixels.Color(red, green, blue));
    } else if (index == fullPixels && partialPercent > 0) {
      pixels.setPixelColor(
        index,
        pixels.Color(
          (static_cast<uint16_t>(red) * partialPercent) / 100,
          (static_cast<uint16_t>(green) * partialPercent) / 100,
          (static_cast<uint16_t>(blue) * partialPercent) / 100));
    } else {
      pixels.setPixelColor(index, 0);
    }
  }
  pixels.show();
#else
  (void)percent;
#endif
}

void handleSerialCommand() {
  static char buffer[48];
  static uint8_t length = 0;

  while (Serial.available()) {
    const char ch = static_cast<char>(Serial.read());
    if (ch == '\n' || ch == '\r') {
      buffer[length] = '\0';
      uint16_t index = 0;
      uint16_t red = 0;
      uint16_t green = 0;
      uint16_t blue = 0;
      uint16_t percent = 0;
      if (sscanf(buffer, "LED %hu %hu %hu %hu", &index, &red, &green, &blue) == 4) {
        setRgb(index, red, green, blue);
      } else if (sscanf(buffer, "QUOTA %hu", &percent) == 1) {
        setQuotaPercent(percent > 100 ? 100 : percent);
      } else if (strcmp(buffer, "CLEAR") == 0) {
        clearRgb();
      }
      length = 0;
    } else if (length < sizeof(buffer) - 1) {
      buffer[length++] = ch;
    }
  }
}

void setup() {
  setupMatrix();
  pinMode(encoderA, INPUT_PULLUP);
  pinMode(encoderB, INPUT_PULLUP);
  pinMode(encoderSwitch, INPUT_PULLUP);

  delay(250);
  lastEncoderState = (digitalRead(encoderA) << 1) | digitalRead(encoderB);
  lastEncoderSwitch = digitalRead(encoderSwitch);

  Keyboard.begin();
  Serial.begin(115200);

#if ENABLE_RGB
  pixels.begin();
  pixels.setBrightness(32);
  pixels.clear();
  pixels.show();
#endif
}

void loop() {
  scanMatrix();
  scanEncoder();
  handleSerialCommand();
}

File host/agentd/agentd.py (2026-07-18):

#!/usr/bin/env python3
"""Small USB CDC RGB test bridge for a multi-agent macro keyboard."""

from __future__ import annotations

import argparse
import sys
import time
from typing import Iterable


COLORS = {
    "idle": (32, 32, 32),
    "thinking": (0, 64, 255),
    "running": (160, 0, 255),
    "waiting": (255, 160, 0),
    "done": (0, 200, 64),
    "error": (255, 0, 0),
}


def load_serial():
    try:
        import serial
        from serial.tools import list_ports
    except ImportError as exc:
        raise SystemExit(
            "pyserial is required; run: pip install -r host/agentd/requirements.txt"
        ) from exc
    return serial, list_ports


def print_ports() -> int:
    _, list_ports = load_serial()
    ports = list(list_ports.comports())
    if not ports:
        print("No serial ports found.")
        return 0
    for port in ports:
        description = port.description or "unknown device"
        print(f"{port.device}\t{description}")
    return 0


def rgb_command(index: int, state: str) -> str:
    try:
        red, green, blue = COLORS[state]
    except KeyError as exc:
        valid = ", ".join(COLORS)
        raise ValueError(f"unknown state {state!r}; use one of: {valid}") from exc
    return f"LED {index} {red} {green} {blue}\n"


def quota_command(percent: int) -> str:
    if not 0 <= percent <= 100:
        raise ValueError("quota percent must be between 0 and 100")
    return f"QUOTA {percent}\n"


def send(ser, line: str) -> None:
    ser.write(line.encode("ascii"))
    ser.flush()
    print(f"> {line.rstrip()}" )


def demo_commands(count: int) -> Iterable[str]:
    states = list(COLORS)
    for offset in range(len(states)):
        for index in range(count):
            state = states[(index + offset) % len(states)]
            yield rgb_command(index, state)
        yield "CLEAR\n"


def main() -> int:
    parser = argparse.ArgumentParser(description=__doc__)
    parser.add_argument("--list", action="store_true", help="list serial ports")
    parser.add_argument("--port", help="serial port, for example /dev/cu.usbmodemXXXX")
    parser.add_argument("--demo", action="store_true", help="run a six-state RGB demo")
    parser.add_argument("--count", type=int, default=6, help="number of RGB LEDs in demo")
    parser.add_argument("--quota", type=int, help="set the 12-LED remaining-quota bar and exit")
    args = parser.parse_args()

    if args.list:
        return print_ports()
    if not args.port:
        parser.error("--port is required unless --list is used")

    serial, _ = load_serial()
    with serial.Serial(args.port, 115200, timeout=0.2) as ser:
        time.sleep(0.5)
        if args.demo:
            for line in demo_commands(max(1, args.count)):
                send(ser, line)
                time.sleep(0.35)
            return 0
        if args.quota is not None:
            send(ser, quota_command(args.quota))
            return 0

        print("Enter `LED <index> <state>`, `QUOTA <percent>`, `CLEAR`, or `quit`.")
        for raw_line in sys.stdin:
            line = raw_line.strip()
            if line.lower() in {"quit", "exit"}:
                break
            if line.upper() == "CLEAR":
                send(ser, "CLEAR\n")
                continue
            parts = line.split()
            if len(parts) == 2 and parts[0].upper() == "QUOTA":
                try:
                    send(ser, quota_command(int(parts[1])))
                except (ValueError, IndexError) as exc:
                    print(exc)
                continue
            if len(parts) != 3 or parts[0].upper() != "LED":
                print("Format: LED <index> <state>")
                continue
            try:
                send(ser, rgb_command(int(parts[1]), parts[2].lower()))
            except (ValueError, IndexError) as exc:
                print(exc)
    return 0


if __name__ == "__main__":
    raise SystemExit(main())

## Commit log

2026-07-18 feat: scaffold 13-key agent controller project
    [bom.csv, codexpad.scad]
2026-07-18 refactor: generalize multi-agent macro keyboard naming
    [agent_macro.scad]
2026-07-18 feat: add Bambu-ready printable models
    [bottom.stl, plate.stl, tolerance_coupon.stl]
2026-07-18 feat: iterate macro keyboard controls and quota lighting
    [agent_macro.scad, bom.csv, bottom.stl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]
2026-07-18 feat: compact keyboard with smooth per-pixel quota lighting
    [agent_macro.scad, bom.csv, bottom.stl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]
2026-07-18 feat: adopt compact panel layout with single encoder
    [agent_macro.scad, bom.csv, bottom.stl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]
2026-07-18 feat: place Arduino Micro under compact key layout
    [agent_macro.scad, bottom.stl, pixel_carrier.stl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]
2026-07-18 feat: split compact macro keyboard into two panels
    [agent_macro.scad, bom.csv, bottom.stl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]
2026-07-18 fix: move controller mount into right-side blank area
    [agent_macro.scad, bottom.stl, plate.stl]
2026-07-18 docs: update bill of materials for right-side controller
    [bom.csv]
2026-07-18 feat: migrate controller interface to USB-C
    [agent_macro.scad, bom.csv, bottom.stl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]
2026-07-18 docs: specify vertical EC11 encoder
    [agent_macro.scad, bom.csv]
2026-07-19 docs: add beginner hardware assembly guide
2026-07-19 feat: move power entry front and add board inspection window
    [agent_macro.scad, bom.csv, plate.stl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]
2026-07-22 fix: tighten EC11 panel opening to fit purchased encoder
    [agent_macro.scad, bom.csv, plate.stl]
2026-07-22 fix: use circular 6mm EC11 shaft opening
    [agent_macro.scad, bom.csv, plate.stl]
2026-07-23 docs: add illustrated beginner soldering guide
2026-07-23 docs: simplify beginner soldering diagrams
2026-07-23 docs: add physical backside soldering diagram
2026-07-23 docs: clarify per-key solder joints
2026-07-23 docs: illustrate shared matrix row wiring
2026-07-23 docs: add complete wiring and assembly overview
2026-07-23 docs: add reference-style wiring poster
2026-07-24 feat: enclose controller in measured USB-C case
    [agent_macro.scad, bom.csv, bottom.stl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]
2026-07-24 docs: add beginner assembly walkthrough video
